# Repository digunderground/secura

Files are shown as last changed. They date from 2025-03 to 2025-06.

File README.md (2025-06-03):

###########################################################################
# Secura - Graflex Lightsaber Chassis - RELEASE
###########################################################################

## Manual 

[READ THE MANUAL HERE](Manual/README.md)

## Craft Cloud Cart 
sample cart, pay attention to the materials. you can use this cart to buy all base parts in the correct materials. 
https://craftcloud3d.com/en/offer/1f019a7e-3fd2-4ae7-9aae-cc49bfd2d0f4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

Lightsaber Render:

secura-render

Lightsaber Stand Render: 

Secura Stand-filled
https://github.com/digunderground/secura/tree/main/STL/Secura-stand

###########################################################################
##  KNOWN ISSUES - This is a WIP!!! 
###########################################################################

- the 33mm speaker (Shtok titan) requires quite a bit of thinning for the enclosure. This likely CANNOT be printed via FDM/SLA/SLS and needs to be done via SLM + nail-biting sanding.
- for FDM/SLA/SLS: you will need to merge the main battery chassis and positive (top) isolation terminal as a single print 

###########################################################################
##  Status
###########################################################################

Current Progress:
- OFFICIAL RELEASE with all assembly edits - 20250518

Past: 
- base F3d files uploaded for closed beta - 20250325
- uploaded STEP Files for non-f360 users - 20250327
- initial open source license in place - 20250325
- WIP BOM file in place for needed parts - 20250325
- pushed STL variants for people without Fusion360 - 20250325
- pushed DXF for laser cut metal pieces - 20250325
- Personal install complete - making some minor updates and will pull the project out of beta.- 20250503
- base proffie config is done and being finalized with wiring diagram - 20250503
- bespoke stand for graflex + chassis - in testing
- added a free open source saber stand for chassis and hilt

TODO:
- Update WIP BOM: tools needed, reformat doc
- direct links to purchasable carts for 3d print services and metal cutting services.
- Find contributor for CFX holder and configs
- Write or collaborate for install manual + exploded drawings etc

### The intention is to print this in SLM metal using services like:
- 316L best price: https://jlc3dp.com/
- Aluminium and other metals: https://craftcloud3d.com/

### Laser Cut metal parts have been tested from:
- https://sendcutsend.com/

### Should you choose to print this using FDM or SLA or SLS, see the notes below: 
For FDM:
- the finished product WILL lack strength in the layer direction
- you WILL lose some of the detail
- we recommend tree supports where necessarry
- you will need to merge some parts into one (positive terminal isolation) and potentially use alternate parts
- you will lose the chassis being a common ground 

For SLA:
- we recommend a 50/50 mixture of Siraya Tech Tenacious Flex and an "ABS Like Resin" - SUNLU works well
- SLA is weaker than most FDM, but has unidirectional strength
- you will need to merge some parts into one (positive terminal isolation) and potentially use alternate parts
- you will lose the chassis being a common ground 

For SLS:
- we recommend this over SLA and FDM, but still inferior to metal
- you will need to merge some parts into one (positive terminal isolation) and potentially use alternate parts
- this is the best budget option if metal is not an option for you.
- you will lose the chassis being a common ground 

###########################################################################
##  License information: 
###########################################################################

Secura Lightsaber Chassis © 2024 by PyxisVeritas LLC. is licensed under Creative Commons Attribution-NonCommercial-ShareAlike 4.0 International 

CC BY-NC-SA 4.0
This license requires that reusers give credit to the creator. 
It allows reusers to distribute, remix, adapt, and build upon the material in any medium or format, for noncommercial purposes only. 
If others modify or adapt the material, they must license the modified material under identical terms.

Additional permissions granted to Installers, Makers, Educational usage, and STEM - details available in:
https://github.com/digunderground/secura/blob/main/LICENSE

BY: Credit must be given to the creator.

NC: Only noncommercial use of your work is permitted.
Noncommercial means not primarily intended for or directed towards commercial advantage or monetary compensation.

SA: Adaptations must be shared under the same terms.

License Deed: 
https://creativecommons.org/licenses/by-nc-sa/4.0/

License Legal: 
https://creativecommons.org/licenses/by-nc-sa/4.0/legalcode.en

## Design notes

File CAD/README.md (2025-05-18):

# CAD files - OFFICIAL RELEASE
############################################################

## Usage of the Fusion 360 files is preferred for all cases

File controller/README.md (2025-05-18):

# Controller config files 
############################################################

## Proffie 3.9:  

- Base configuration for the Proffie 3.9 is live. you will need to read, understand, and add your own style functions

## TODO: 

- we need a collaborator for CFX config and model changes for CFX
- any other sound boards TBD

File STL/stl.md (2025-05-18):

# STL - Print details
###########################################################################
## Secura Chassis: 

- SLM: Any files with "ISO" in the file name should be printed in PLASTIC, they are isolation parts. DO NOT print in metal.  
- FDM/SLA you will need to merge the "CH-ISO_Battery.stl" into the main chassis
- FDM/SLA OPTIONAL: you can merge the proffie to the chassis 

## Secura Crystal Chamber: 

- SPG-window needs to be printed in CLEAR RESIN or other clear material 

## Secura Speaker: 

- SP files with "holder" in the name need to be printed in CLEAR RESIN if you want to see the lights

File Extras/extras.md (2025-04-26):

will add aupporting model files here
- board configurator will be uploaded 2025-04-26

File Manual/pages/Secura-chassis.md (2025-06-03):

# Secura Chassis 
_electronics and battery_
***
## Navigation: [Manual](../README.md) / Secura-chassis.md
***
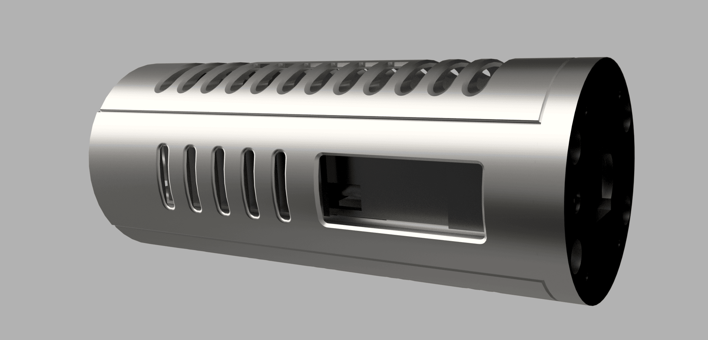
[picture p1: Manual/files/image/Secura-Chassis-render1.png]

***
https://github.com/user-attachments/assets/cefb1376-12e1-43ca-87cb-c5749daabf90
***
## Chassis Part Highlights: 
> [!CAUTION]
> All parts with "..ISO.." in the name are isolation parts and must be printed in approved plastics

> [!IMPORTANT]
>It is our strong recommendation to have the chassis parts SLM printed from metal 

***

## TOC 
[Manual](../README.md) / Secura-chassis.md
***
### 1) Isolation parts - print out of a non-conductive material 
- [CH-ISO_Battery ](#ch-iso_battery)
- [CH-ISO_Proffie](#ch-iso_proffie)
- [CH-ISO_BusBar](#ch-iso_busbar)
- [CH-ISO_screen](#ch-iso_screen) 

### 2) Main Body Parts - SLM > SLS > SLA or FDM 
- [CH-base](#ch-base)
- [CH-electronicsDoor](#ch-electronicsdoor)
- [CH-chassis](#ch-chassis)
- [CH-batteryDoor](#ch-batterydoor)

> [!CAUTION]
> DO NOT PRINT CH-batteryTerminal. this is for sizing and comparison - [CH-ISO_Battery ](#ch-iso_battery) has a full description.

## CH-ISO_Battery
***
[to TOC &uarr;](#toc)
***
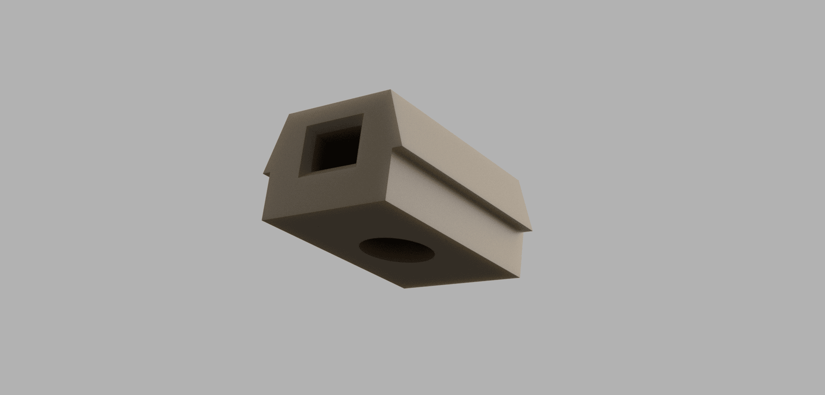
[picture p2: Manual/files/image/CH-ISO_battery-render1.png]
 
> [!IMPORTANT]
> If you choose to print the entire chassis out plastic instead of metal, this part will need to be merged into the CH-chassis part for ideal rigidity.

The CH-ISO_battery part isolates the battery positive contact from the SLM metal chassis. You will need a piece of 5mm Copper rod to cut a positive battery contact out of, you can use a dremel tool to do this. 
Once the positive terminal is cut out it can be notched and soldered to the wire, then pressed into the CH-ISO-Battery part with the wire exiting the rectangular hole in the rear. 
- we recommend printing this part out of PA12 or PA6 using a SLS method 
- alternatively you can FDM print from PA12 or ABS/ASA 

## CH-ISO_Proffie
*** 
[to TOC &uarr;](#toc)
***
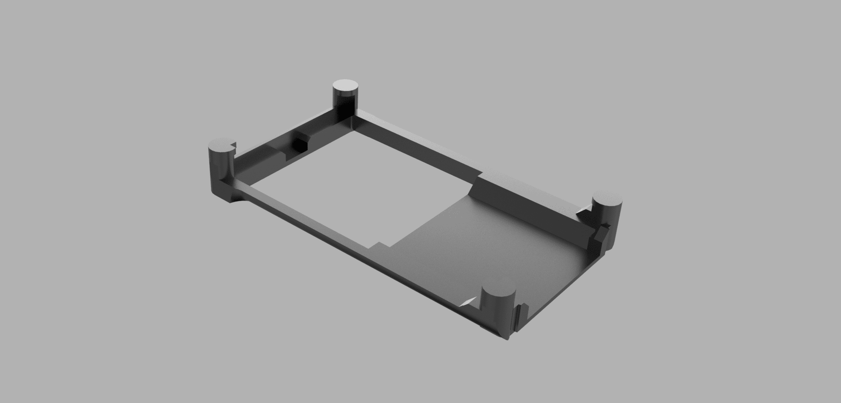
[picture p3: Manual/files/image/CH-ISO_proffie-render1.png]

> [!NOTE]
> The Proffie is mounted with the SD card facing the mount. 

The CH-ISO_proffie part isolates the proffie from the SLM metal chassis. The proffie board is a snug fit, some filing or clipping to the "posts" may be needed depending on the printer accuracy.
this part can be glued to the chassis body (CH-chassis) to improve rigidity, but it will press into place as-is. 
- we recommend printing this part out of PA12 or PA6 using a SLS method
- alternatively you can FDM print from PA12 or ABS/ASA

## CH-ISO_BusBar
***
[to TOC &uarr;](#toc)
***
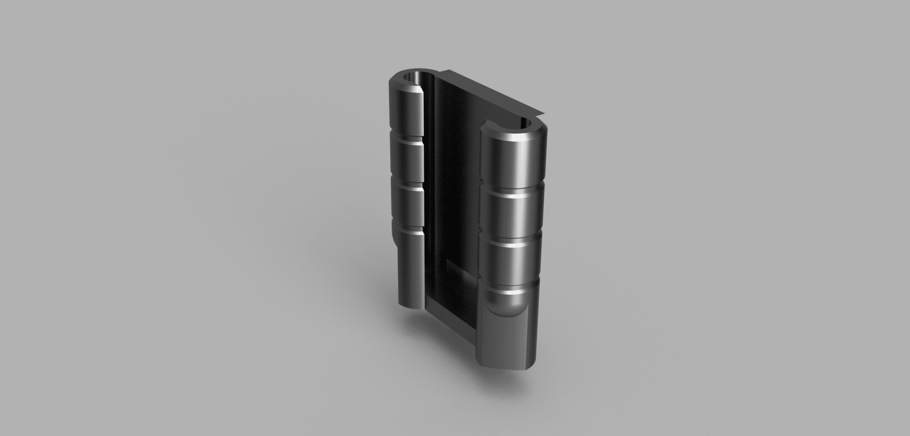
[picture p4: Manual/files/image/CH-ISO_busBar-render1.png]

> [!TIP]
> this is an OPTIONAL part 

The CH-ISO_busBar part is optional, it is intended to use 2x 3mm copper tubes as the positive and negative common. This allows installers to have a clean way to tie multiple leads to positive or negative to drive various components. 
this can wholly be omitted in favor of wire heat shrink and tucking. 
Should you choose to use this part you will need 3mm thick wall copper tubing, cut to length and solder points cut/drilled in the tube to support the number of connections you need. 

## CH-ISO_Screen
*** 
[to TOC &uarr;](#toc)
***
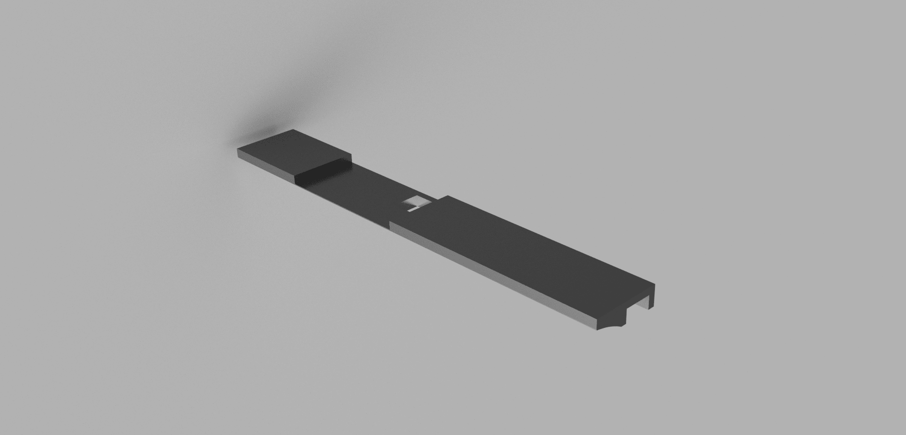
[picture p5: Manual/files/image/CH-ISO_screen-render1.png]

> [!NOTE]
> The screen is mounted to the topside with wires running behind it. additionally, a LED strip can be affixed to the top side to show through the chassis venting. 

The CH-ISO_screen part is to keep the OLED isolated from the SLM metal chassis body. it also allows the wires to run behind it, concealing them from view. This part provides a snug fit for the screen against the main chassis. 
> [!TIP]
> you may need to sand down thi part of a perfect fit depending on how much finish work you put into the SLM metal body. 

## CH-base
*** 
[to TOC &uarr;](#toc)
***
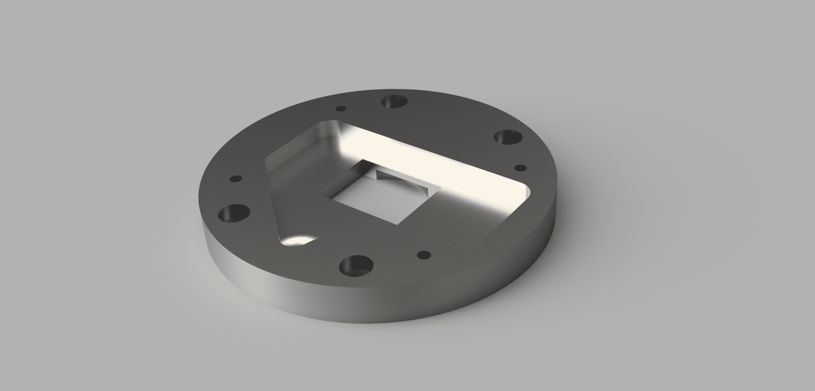
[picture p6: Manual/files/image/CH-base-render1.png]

> [!IMPORTANT]
> you will need to tap 4x M1.4 holes in this piece to hold the speaker enclosure 

> [!TIP]
> Assemble calls for 4x 4-40 heatset inserts - these are NOT heat set into the parts, it is instead used as a very small nut that will easily recess into the part when assembled. 

The CH-base part caps off the bottom end of the chassis assembly and allows the speaker holder to be secure screwed in using 4x M1.4 screws. This part has an opening that you can mount a single LED or small Shtok LED ring into. 
the recessed side (in the image) goes towards the chassis, this area is to allow easy routing of electronics and wires

## CH-electronicsDoor
*** 
[to TOC &uarr;](#toc)
***
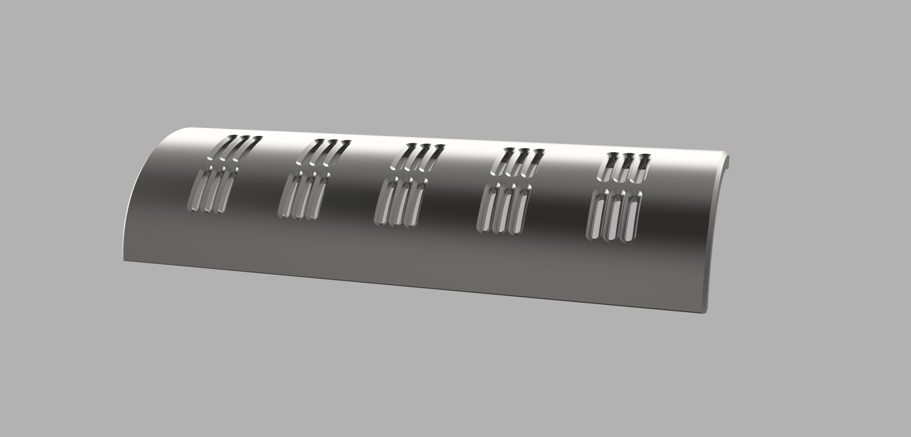
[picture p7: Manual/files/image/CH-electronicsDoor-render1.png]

> [!NOTE]
> This part is NOT interchangable with the CH-batteryDoor

> [!TIP]
> you will need to glue in 6x neodymium magnets - 3mm diameter 1mm thick 

This part covers the electronics of the chassis, it is held on with 6x neodymium magnets that you need to glue in. be VERY cautious during install to keep the magnets in the correct orientation so they do not repel the magnets in the CH-chassis part - these small magnets really like to flip flop. 

## CH-chassis
*** 
[to TOC &uarr;](#toc)
***
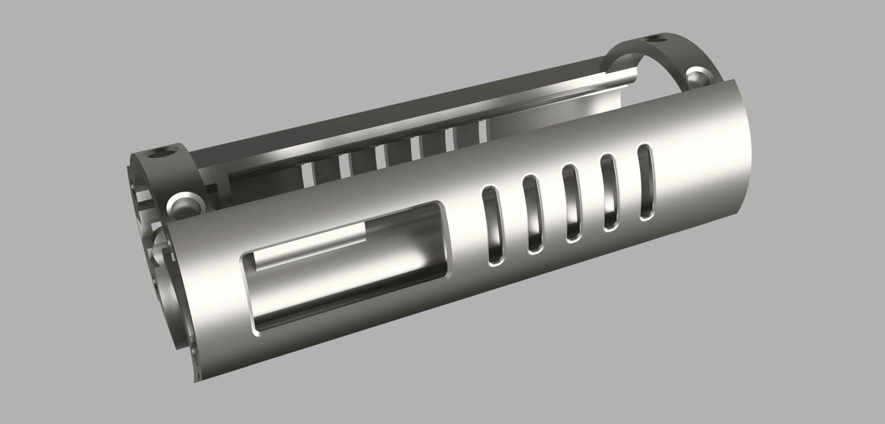
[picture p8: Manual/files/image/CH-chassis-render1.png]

> [!NOTE]
> This will require 10x neodymium magnets 3mm diameter x 2mm thick 

The CH-chassis part is the main event, here to house all electronics and wiring. it is a tight fit and will test your patience from time to time. 

## CH-batteryDoor
*** 
[to TOC &uarr;](#toc)
***
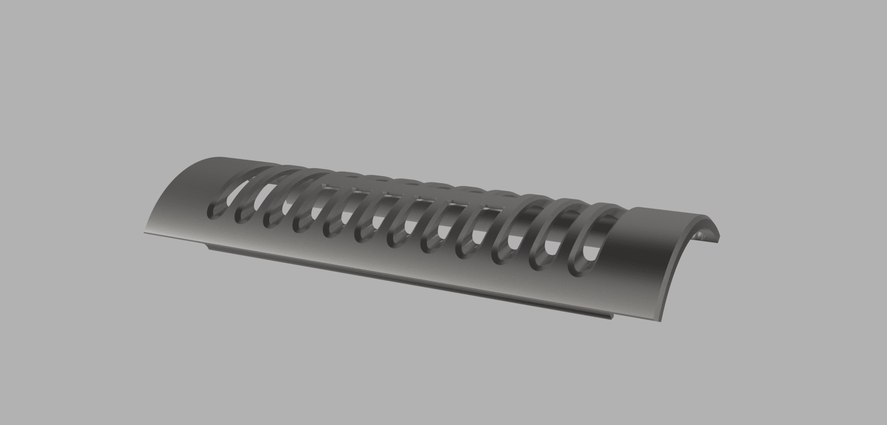
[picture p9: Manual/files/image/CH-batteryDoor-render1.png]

> [!NOTE]
> This part is NOT interchangable with the CH-electronicsDoor

> [!TIP]
> you will need to glue in 4x neodymium magnets - 3mm diameter 1mm thick

This part covers the battery within chassis, it is held on with 4x neodymium magnets that you need to glue in. Be VERY cautious during install to keep the magnets in the correct orientation so they do not repel the magnets in the CH-chassis part - these small magnets really like to flip flop.

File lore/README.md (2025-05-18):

https://github.com/user-attachments/assets/b904147c-5c41-4c31-8f6f-022a52ba4b2a

# SECURA LORE 
################################################################

As a Padawan, Anakin Skywalker built his first lightsaber with great pride, believing it to be the finest weapon crafted by any Jedi. It did not last. In the depths of a Separatist droid foundry on Geonosis, he lost it—severed by a mechanical cutting arm as easily as the factory carved its machines of war. That was the nature of Anakin Skywalker: to build something powerful, only to lose it in his recklessness.

When the time came to construct a second saber, Anakin sought perfection. He had seen battle by then, had fought alongside Jedi whose skills in lightsaber construction surpassed his own. Among them was Aayla Secura. She was not merely a warrior—she was an artist with a blade, both in combat and in its design. Unlike most Jedi, who constructed their weapons once and rarely modified them, Aayla refined hers constantly, always improving its internals. She had developed a specialized chassis system, reinforcing the weapon’s power flow with stabilizers that increased energy efficiency and minimized strain on the Kyber crystal. This allowed her lightsaber to maintain perfect balance in combat, the energy output steady and unyielding even under extreme conditions. It was built for endurance, for adaptability—something that intrigued Anakin greatly.

Between battles, he studied her weapon closely, often asking questions about its construction. At first, she humored him, explaining the intricacies of her modifications. But as time passed, she realized he was not merely curious—he was absorbing everything she said, eager to apply it to his own work. He spent hours in quiet observation, watching how she fine-tuned the chassis, how she adjusted the focusing crystal to prevent degradation, how the modular framework allowed for easy repair and adaptation. It was a level of craftsmanship beyond his own at the time, and though he would never openly admit it, Aayla had become an unintentional mentor to him.

But Aayla's time in the war was not endless. On Felucia, as Order 66 was enacted, betrayal struck swiftly. Commander Bly and his troops turned on her without hesitation, their blasters raining fire upon her. With no time to defend herself, Aayla fell, her body left behind as the clones marched on. Her lightsaber, a testament to her ingenuity and skill, was lost to the jungle.

Anakin survived, though not as the Jedi he had once been. When he built his second lightsaber, he drew upon the lessons he had learned from Aayla. It was no mere reconstruction of his first weapon; it was stronger, more efficient, its internal architecture stabilized by principles he had taken from her work. It carried echoes of her innovations, a silent tribute to a Jedi he would never fight alongside again. He wielded it through victories and defeats, through moments of heroism and the first whispers of his fall.

Then, on Mustafar, the weapon fell from his grasp as Obi-Wan Kenobi struck him down. His former Master, standing above him on the lava banks, did not hesitate—he took the lightsaber, knowing its importance. But as he held it, he felt something deeper than just Anakin’s presence. He had fought alongside Aayla in the Clone Wars, had seen her skill firsthand, and as he turned the weapon in his hands, he recognized elements of her craft woven into its construction. This was no ordinary blade. It had passed through the hands of warriors who had shaped the fate of the Republic.

Obi-Wan fled to Tatooine, taking the lightsaber with him. He could not bring himself to destroy it, nor could he wield it himself—it was not his to bear. Instead, he hid it away, keeping it safe until the time was right. In exile, he often thought of the past—of Anakin, of Aayla, of all the Jedi lost to the Empire. He knew the lightsaber would one day have a purpose, that it would not remain buried forever.

And when the time came, and he placed it in the hands of Luke Skywalker, he did so knowing it was more than just a weapon. It was a legacy—not just of Anakin Skywalker, but of Aayla Secura, of the Jedi who came before, of the fight to restore balance to the Force. The saber had passed through war and betrayal, through loss and exile. Now, it would help guide the galaxy toward hope once more.

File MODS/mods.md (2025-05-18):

# MODS - all USER content / Contributions
###################################################################

## Rules: 

### For Mods: 
- branch and check out main codebase
- create a folder withing /MODS/ using your GIT username. IE: /MODS/myUserName/
- keep the root folder structure 
- make your mods/edits/changes/contributions

### For updates to the core (fixes, QOL): 

- ONLY if you want to have a feature pulled into MAIN:
  - post a PR (pull request) for a branch 
  - only include the changes you are recommending that fix a base feature 
  - have VERY detailed GIT check in comments - this will make or break your request!!!!

### OVERALL: 
- be patient, we are a small team. wait for approval and validation. 
- In some cases, mods will be merged back to the main project and you may be invited as a contributor.

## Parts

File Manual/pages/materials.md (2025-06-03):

# Materials
***
## Navigation: [Manual](../README.md) / materials.md 
***
## TOC
[Manual](../README.md) / materials.md
- [FDM / SLS Materials ](#fdmsls-materials)
- [Metal Materials](#metal-materials) (SLM)
- [Resin Materials](#resin-materials)

***
## FDM/SLS materials 
***
> [!IMPORTANT]
> - Ideally FDM/SLS are only used for the ISO (isolation) parts
> - A full SLS/FDM chassis will work but will be significantly less rigid.
> - you will need to merge some parts for a full resin chassis.

| **MATERIAL** | **METHOD** | **APPROVAL** | **TESTED** | **NOTES** |
|---|---|---|---|---|
| PA12 | SLS/FDM | YES | YES | non-condustive, resistant to heat, does not deform over time |
| PA6 | SLS/FDM | YES | YES | non-condustive, resistant to heat, does not deform over time |
| ABS | FDM | YES | YES | non-condustive, resistant to heat, does not deform over time |
| ASA | FDM | YES | YES | non-condustive, resistant to heat, does not deform over time |
| PLA | FDM | NO | YES | Non-Condustive, deforms under heat, deforms over time |
| PETG | FDM | NO | YES | Non-Conductive, Handles heat well, deforms over time, not ideal |
| ANY Carbon Reinforced | SLS/FDM | NO | YES | POTENTIALLY conductive - DO NOT USE |
| PC (polycarbonate) | FDM | YES | YES | non-condustive, resistant to heat, does not deform over time |
| PEEK | FDM | YES | NO | Of course this will work, you are borderline crazy |

> [!NOTE]
> This is NOT an exhaustive list, other materials may work.
> List will be updated over time

[to TOC &uarr;](#toc)

## Metal materials
***

> [!IMPORTANT]  
> - we have only tested SLM due to its strength and ability to be machined if needed. 
> - we have NOT tested DMLS / LMM / DMP / or Binder Jet - due to costs, availability or known limitations

| **MATERIAL** | **METHOD** | **IMPACT** | **TESTED** | **NOTES** | **EXAMPLE COST** |
|---|---|---|---|---|---|
| Stainless 316 | SLM | Harder | YES | Durable, difficult to work with, moderate expense | $180 |
| Aluminum | SLM | Easy | YES | Moderately Durable, easy to work with, low expense | $160 |
| Brass | SLM | Expensive  | NO | Moderately durable, easy to work with, very high expense | over $1000 |
| Copper | SLM | Expensive  | NO | Moderately durable, difficult to work with, very high expense | over $1000 |
| Bronze | SLM | Expensive  | NO | Durable, difficult to work with, very high expense | over $1000 |
| Titanium | SLM | Expert | YES | Extremely durable, very difficult to work with, high expense  | $675 |

> [!NOTE]
> This is NOT an exhaustive list, other materials may work.
> List will be updated over time

[to TOC &uarr;](#toc)

## Resin materials
***
> [!IMPORTANT]
> - Resin should NOT used for the ISO (isolation) parts due to their tendency to fracture
> - A full resin chassis will work but will be significantly less rigid and prone to cracking.
> - you will need to merge some parts for a full resin chassis.

| **MATERIAL** | **METHOD** | **APPROVAL** | **TESTED** | **NOTES** |
|---|---|---|---|---|
| Nylon Like | SLA | YES | YES | relatively durable, less prone to cracking |
| ABS Like | SLA | YES | YES | relatively durable, less prone to cracking |
| Siraya Tech Tenacious Flex | SLA | NO | YES | difficult to print details, durable, flexible |
| 50/50 ABS/Siraya Tech Tenacious Flex | SLA | YES | YES | durable, relatively easy to print, best option for SLA |
| RESIONE G217 Clear ABS-Like Resin | SLA | CLEAR ONLY | YES | Great for clear parts after sanding and polishing, not recommended for the full chassis |

> [!NOTE]
> This is NOT an exhaustive list, other materials may work.
> List will be updated over time

[to TOC &uarr;](#toc)

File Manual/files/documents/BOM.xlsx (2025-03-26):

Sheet: Hardware
Required | Related part | Description | Supplier | SKU/Model | URL | Cost | Quantity | Notes:
yes | side switch - emitter | Lever Microminiature Microswitch SPDT Body dimensions: 8.3 x 6.5 x 2.7mm (height x length x width) | switchelectronics | SKU: 483501 MPN: 483501 | https://www.switchelectronics.co.uk/products/lever-microminiature-microswitch-spdt?variant=45339140423989 | $1.25 | 1 | price per. Extras are always a good idea.
optional | crystal chamber top/bottom | Splined Press-Fit Threaded Standoffs 4-40 | McMaster Carr | 92985A110 | https://www.mcmaster.com/catalog/131/3746/92985A110 | $14.70 | 1 | pack of 25
yes | emitter button | Titanium Phillips Flat Head Screws | McMaster Carr | 90233A400 | https://www.mcmaster.com/catalog/131/3496/90233A400 | $1.52 | 1 | extras are always good
optional | crystal chamber top/bottom | Titanium Unthreaded Spacers | McMaster Carr | 98721A112 | https://www.mcmaster.com/catalog/131/3729/98721A112 | $4.08 | 24
yes | Speaker holder | M1.4 316 Stainless Steel Socket Head Screws | McMaster Carr | 92290A846 | https://www.mcmaster.com/catalog/131/3569/92290A846 | $13.43 | 1 | pack of 25
yes | speaker cover | m1.4 18-8 Stainless Steel Slotted Flat Head Screws | McMaster Carr | 91430A156 | https://www.mcmaster.com/catalog/131/3503/91430A156 | $12.00 | 1 | pack of 10
yes | chassis | Micro Momentary Tactile Push Button Switch Tact Assortment Kit | Amazon | 602318745965 | https://www.amazon.com/dp/B07LCBLB8N?ref_=ppx_hzsearch_conn_dt_b_fed_asin_title_2&th=1 | $9.49 | 1 | more than you need
yes | chassis | Proffieboard v3.9 Soundcard | thecustomsabershop | Proffieboard v3.9 | https://www.thecustomsabershop.com/Electronics/Sound-Modules/Proffieboard-v39-Soundcard | $48.00 | 1 | any vendor is acceptible
yes | chassis | 4W 28mm WOWSpeaker | thecustomsabershop | 28mm speaker | https://www.thecustomsabershop.com/Electronics/Speakers/28mm-Speakers/4W-28mm-WOWSpeaker | $12.95 | 1 | this fits, others may work
yes | blade holder | NPXL V3 Hilt side PCB connector - Long Pins | thecustomsabershop | NPXL V3 | https://www.thecustomsabershop.com/Blades/Pixel-Blades/Pixel-Blade-Components/NPXL-Style-Connector/NPXL-V3-Hilt-side-PCB-connector-Long-Pins | $15.10 | 1 | others may fit
yes | blade holder | 1" NPXL V3 Hilt Side Adapter | thecustomsabershop |  | https://www.thecustomsabershop.com/Blades/Pixel-Blades/Pixel-Blade-Components/NPXL-Style-Connector/1-NPXL-V3-Hilt-Side-Adapter | $4.20 | 1
yes | chassis | USB-C Breakout Board | thecustomsabershop |  | https://www.thecustomsabershop.com/Electronics/Batteries-and-Packs/Clips-Connectors/USB-C-Breakout-Board | $5.50 | 1
yes | chassis | OLED screen | thecustomsabershop |  | https://www.thecustomsabershop.com/Electronics/Sound-Modules/OLED-Screen-Blue | $6.25 | 1
yes | Crystal chamber | 2.7mm Ultra Narrow LED Strip | Amazon |  | https://www.amazon.com/dp/B0CYGHHR96?ref=ppx_yo2ov_dt_b_fed_asin_title&th=1 | $15.99 | 1
yes | chassis | 8650 Battery Negative to Positive Conversion Spring Contact | Amazon |  | https://www.amazon.com/uxcell-Negative-Conversion-Nickeling-16-5mmx16mm/dp/B07HRTMY5T | $12.19 | 1
yes | chassis | #3-48 Tap and #47 Drill Bit Kit | Amazon |  | https://www.amazon.com/dp/B071D7FWC9?ref=ppx_yo2ov_dt_b_fed_asin_title | $8.13 | 1
yes | chassis | #4-40 Tap and #43 Drill Bit Kit | Amazon |  | https://www.amazon.com/dp/B071DHVB6S?ref=ppx_yo2ov_dt_b_fed_asin_title&th=1 | $10.13 | 1
yes | crystal chamber | 4-40 Tapered, Thru-Threaded, 4.4 mm OD, 3.4 mm Length | Amazon |  | https://www.amazon.com/dp/B08WC192B9?ref=ppx_yo2ov_dt_b_fed_asin_title | $15.98 | 1
yes | crystal chamber | 6mm Mini Micro Planetary Reduction High Electric Micro Speed Reduction Gear Motor DC3V Motor(Three Stage) | Amazon |  | https://www.amazon.com/dp/B0863D37XN?ref=ppx_yo2ov_dt_b_fed_asin_title | $12.87 | 1
 |  |  |  |  |  | $223.76

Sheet: 3D part Supplier
Supplier | Material | Process | parts | Cost | Notes:
https://craftcloud3d.com/ | Aluminum | SLM | chassis | $180.00 | electro anodize for additional colors
 | 316L | SLM | chassis | $330.00
 | Titanium | SLM | chassis | $740.00
 | Copper/brass/bronze | SLM | chassis | $1800.00 | starts at $1800 - ranges to a used car. Use TI instead and anodize
 | PA12 | SLS | isolation | $22.00
 | Transparent resin | SLA | speaker holder | $40.00 | worst price
https://jlcpcb.com/ | 316L | SLM | chassis | $163.00 | by far the best pricing, long lead time
 | PA12 | SLS | isolation | $2.00 | best pricing
 | transparent resin | SLA | speaker holder | $2.40 | best pricing

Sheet: Wiring
Device | Proffie 3.9 Pins | Description | wire type | Gauge | Notes
Main Blade |  |  |  |  | Designed for up to 20A (quad pixel blde)
 | (22) LED 3 | negative | PTFE | 18
 | (22) LED 2 | negative | PTFE | 18
 | BUS | positive | PTFE | 18
 | (6) Data 4 | Data | PTFE | 30 | blade removal
 | (0,1) Data1/ID | Data |  | 30
SPG LED | (20) LED1 | Negative |  | 30
 | Data2 (2,3) | Data |  | 30
 | BUS | positive |  | 30
Button (main) | BUS | Negative |  | 30
 | Button1 (11,12) | positive |  | 30
Button (side) | BUS | Negative |  | 30
 | (13,14) button2 | positive |  | 30
OLED | SDA (18) | Data |  | 30 | Connects to SCK on OLED
 | SCL (19) | Data |  | 30 | Connects to SDA on OLED
 | SD Power | Positive |  | 30
 | BUS | Negative |  | 30
Speaker | Speaker + | Positive |  | 28
 | Speaker - | Negative |  | 28
Crystal Chamber LED | BUS | Positive |  | 30
 | LED6 (25) | Negative |  | 30
 | Data3 (4,5) | Data |  | 30
SPG motor (3 step) | 3.3v | Positive |  | 30
 | LED4 (23) | Negative |  | 30
Speaker LED | (24) LED5 | Negative |  | 30
 | BUS | Positive |  | 30
 | Free3 (9,10) | Data |  | 30 | Free1 (7) alt

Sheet: Open Source License
https://creativecommons.org/licenses/by-nc-sa/4.0/
Secura Lightsaber Chassis © 2024 by PyxisVeritas LLC is licensed under Creative Commons Attribution-NonCommercial-ShareAlike 4.0 International

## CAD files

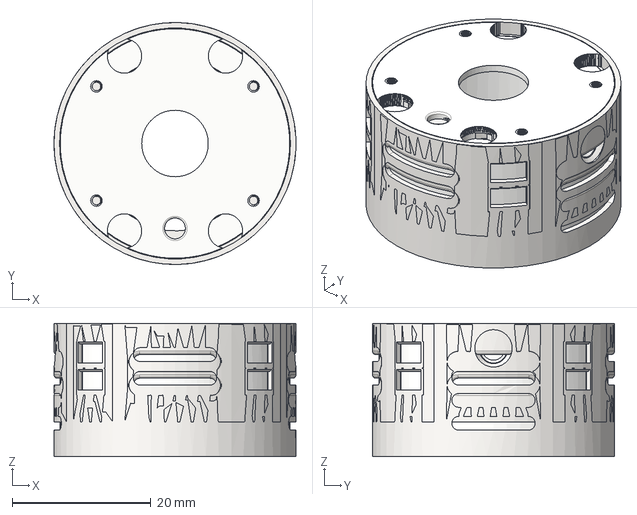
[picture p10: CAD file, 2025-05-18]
CAD/STEP/Secura-Speaker.step
34.9 x 34.9 x 19.2 mm

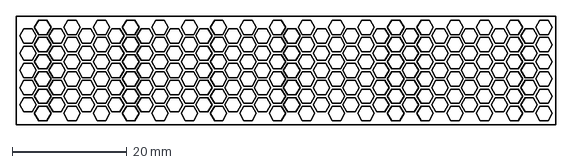
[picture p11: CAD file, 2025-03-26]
DXF/Secura-pg-hex-mesh.dxf
94.0 x 19.0 mm

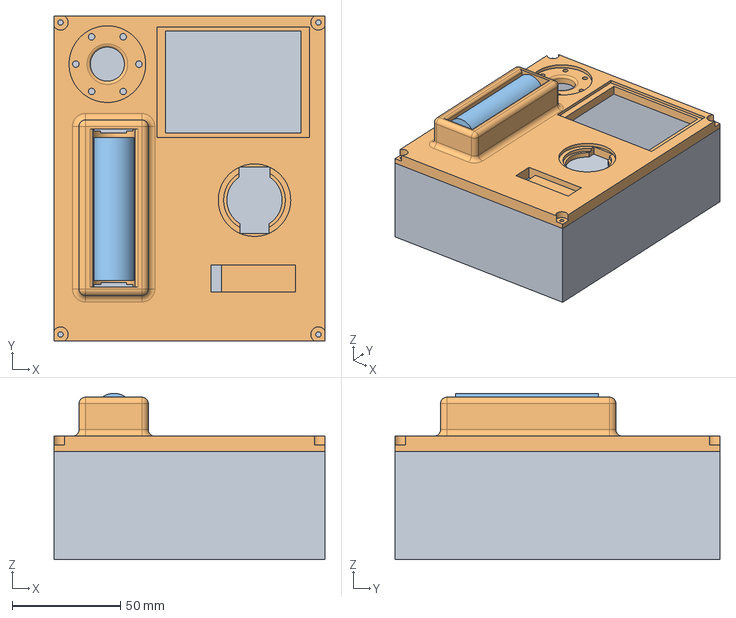
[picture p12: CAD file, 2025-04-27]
Extras/proffieTester/STEP/wiring_tester_v5_wiring_tester_v5.step
125.0 x 150.0 x 76.7 mm

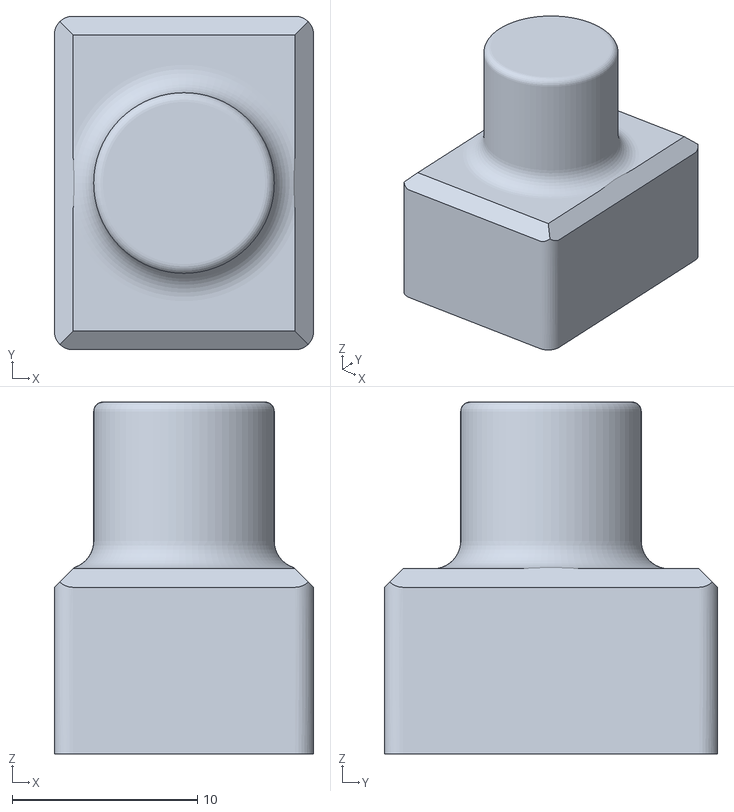
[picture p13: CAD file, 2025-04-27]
Extras/proffieTester/STL/wiring_tester_v5_magnet.stl
14.0 x 18.0 x 19.0

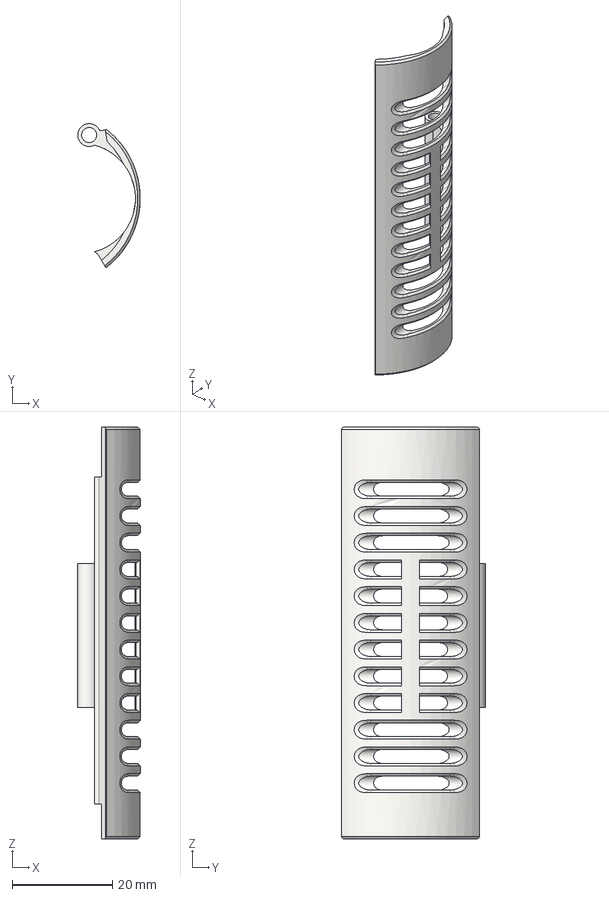
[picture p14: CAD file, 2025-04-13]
MODS/Digunderground/experimental/Secura-chassis/Secura-CH-EXP-21700-batteryDoor.step
12.4 x 28.6 x 82.0 mm

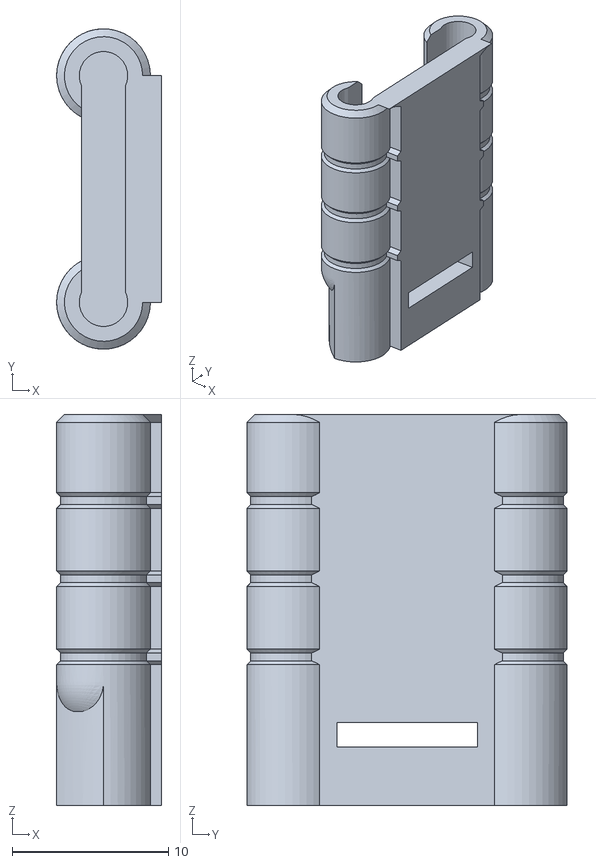
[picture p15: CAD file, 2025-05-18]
STL/Secura-chassis/CH-ISO_bus_bar.stl
6.70 x 20.5 x 25.0

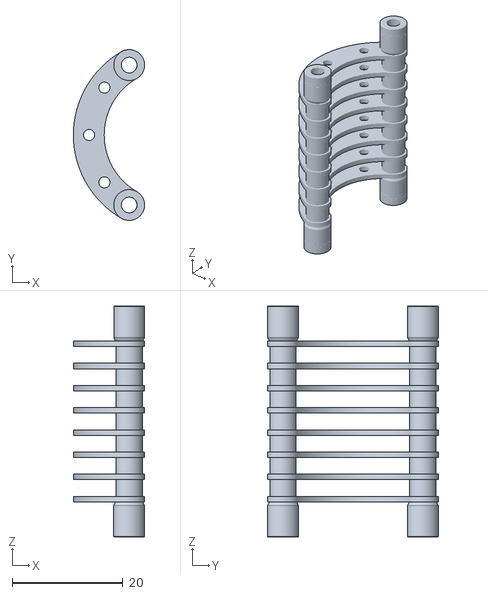
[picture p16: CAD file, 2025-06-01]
STL/Secura-crystalChamber/NOP/NOP-CC-fins-l.stl
12.8 x 30.8 x 41.6

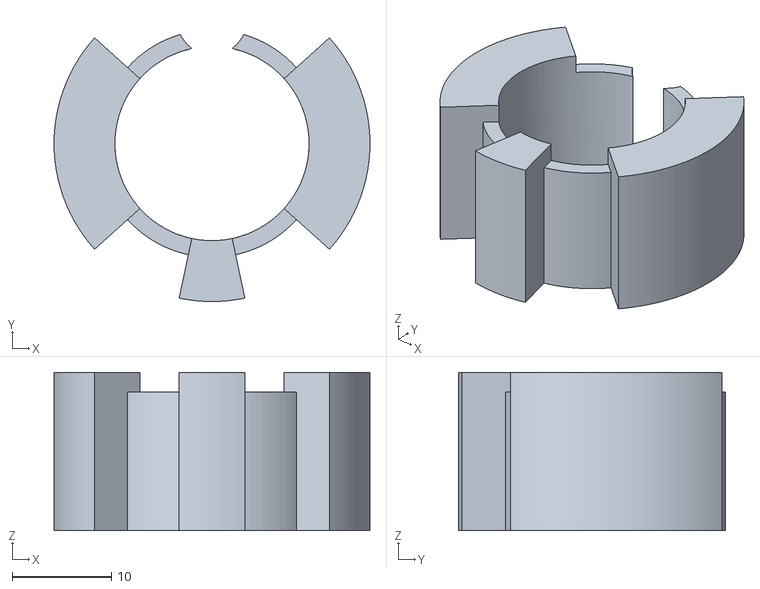
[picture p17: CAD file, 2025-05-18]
STL/Secura-crystalChamber/SPG-window.stl
31.9 x 27.0 x 16.0

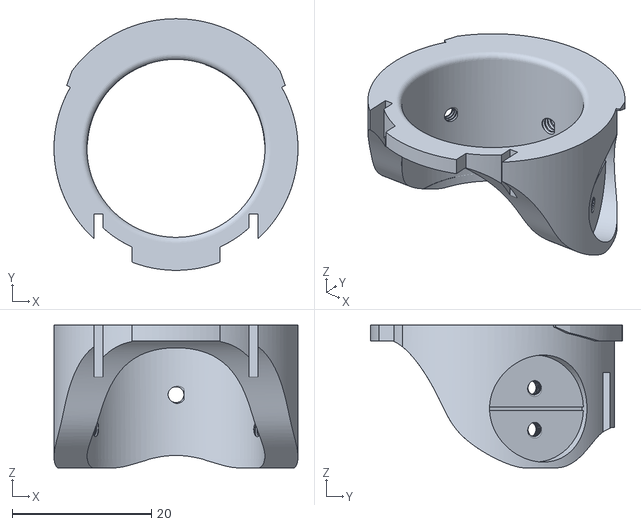
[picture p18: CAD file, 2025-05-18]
STL/Secura-emitter/EM-topAccurate.stl
35.1 x 36.2 x 20.5

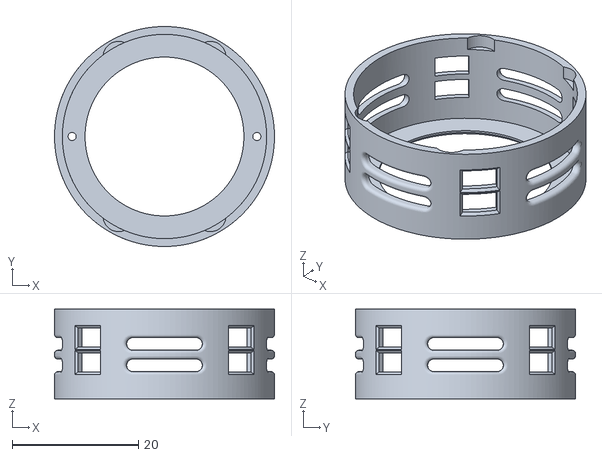
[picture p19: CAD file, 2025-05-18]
STL/Secura-speaker/28mm/SP-28mm-outer.stl
34.9 x 34.9 x 14.2

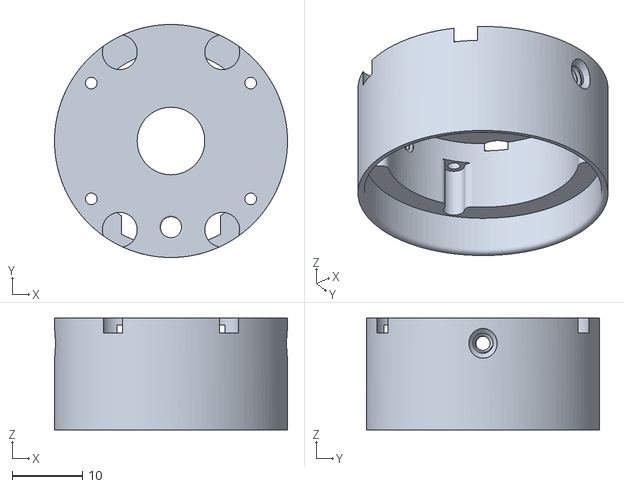
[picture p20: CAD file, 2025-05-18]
STL/Secura-speaker/33mm/SP-33mm-holder.stl
33.1 x 33.1 x 15.9

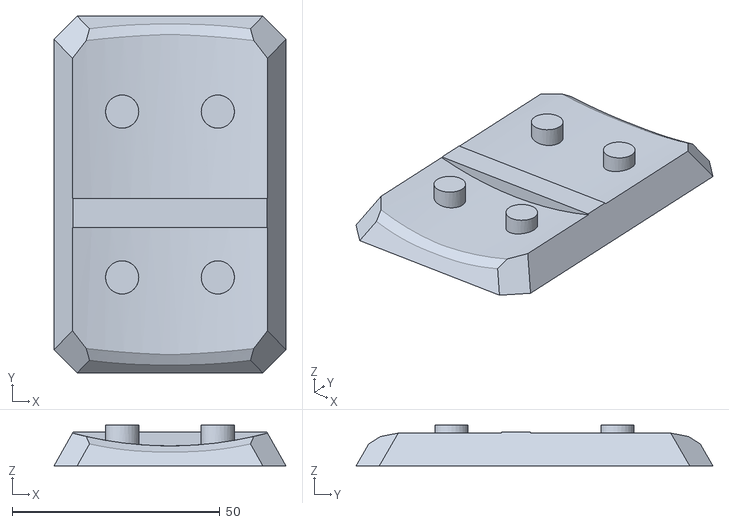
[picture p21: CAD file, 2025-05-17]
STL/Secura-stand/SS-arcHolder.stl
55.8 x 85.9 x 9.80

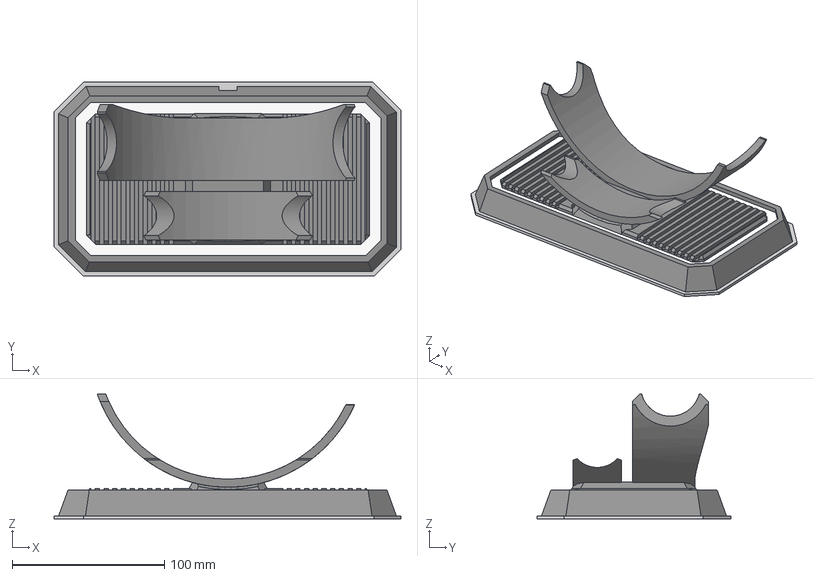
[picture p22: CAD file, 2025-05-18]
CAD/STEP/Secura-stand.step
227.6 x 127.4 x 81.9 mm

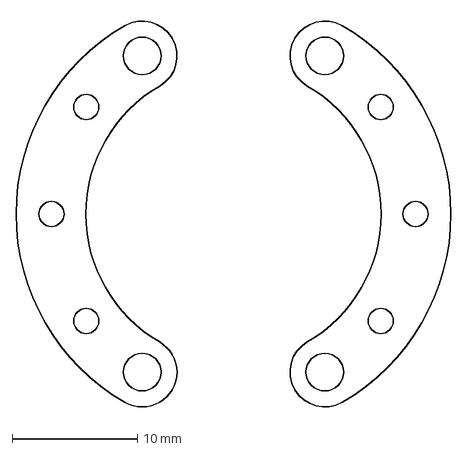
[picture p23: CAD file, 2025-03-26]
DXF/Secura-cc-fins.dxf
34.7 x 31.6 mm

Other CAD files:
Extras/proffieTester/STL/wiring_tester_v5_test-bottom.stl
MODS/Digunderground/experimental/Secura-chassis/Secura-CH-EXP-21700-Chassis.step
STL/Secura-chassis/CH-chassis.stl
STL/Secura-crystalChamber/NOP/NOP-CC-fins-r.stl
CAD/Fusion360/Secura-Chassis.f3d
CAD/Fusion360/Secura-CrystalChamber.f3d
CAD/Fusion360/Secura-Emitter.f3d
CAD/Fusion360/Secura-Speaker.f3d
CAD/Fusion360/Secura-stand.f3d
CAD/STEP/Secura-CrystalChamber.step
Extras/proffieTester/STL/wiring_tester_v5_faux-18650.stl
Extras/proffieTester/STL/wiring_tester_v5_test-top.stl
MODS/Digunderground/STL/Secura-emitter/EM-base-thumbScrew.stl
MODS/Digunderground/experimental/Secura-chassis/CH - Chassis-21700.stl
MODS/Digunderground/experimental/Secura-chassis/CH - battery door- 21700.stl
STL/Secura-chassis/CH-ISO_Battery.stl
STL/Secura-chassis/CH-ISO_Proffie.stl
STL/Secura-chassis/CH-ISO_screen.stl
STL/Secura-chassis/CH-base.stl
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

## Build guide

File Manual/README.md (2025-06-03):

# Secura Chassis Manual
***
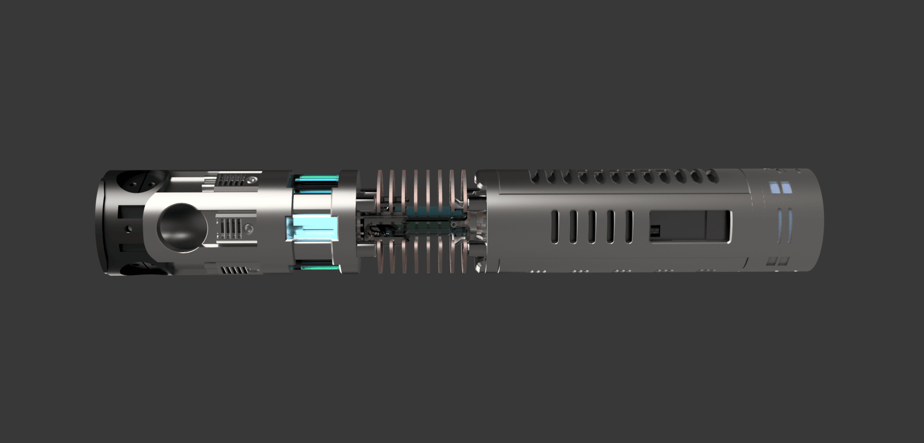
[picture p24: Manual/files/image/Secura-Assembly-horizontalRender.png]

## Main Chassis Parts: 
This manual will be broken into sections for each main component and their assembly details. 
There will be additional sections for various other assembly and wiring needs. 
***

> [!IMPORTANT]
> - Files OR Folders with NOP mean "NoPrint" - these are for reference or people who want to print these parts instead of using hardware or laser cut parts. These are generally untested in a printable form and intended to use parts from the BOM instead. 

## Glossary: 

- ### Part descriptions and details 
  - [Secura Chassis ](pages/Secura-chassis.md)
  - [Secura Crystal Chamber and Plasma Gate](pages/Secura-crystalChamber.md)
  - [Secura Emitter ](pages/Secura-emitter.md)
  - [Secura Speaker](pages/Secura-speaker.md)
- ### Assembly Documentation 
  - #### General 
    - [Materials](pages/materials.md) (Recommended 3d printing materials)
    - [Tools and Consumables](pages/tools-consumables.md) (recommended Tools)
    - Finishing Parts
    - [Wiring](pages/wiring.md)
    - Tapping
    - Suppliers
  
  - #### Secura Chassis Assembly 
    - [Secura Chassis ](pages/Secura-chassis-assembly.md)
    - [Secura Crystal Chamber and Plasma Gate](pages/Secura-crystalChamber-assembly.md)
    - [Secura Emitter ](pages/Secura-emitter-assembly.md)
    - [Secura Speaker](pages/Secura-speaker-assembly.md)

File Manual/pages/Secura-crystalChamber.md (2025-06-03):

# Secura Crystal Chamber
_Blade holder, buttons and chassis side blade pins_
***
## Navigation: [Manual](../README.md) / Secura-crystalChamber.md
***
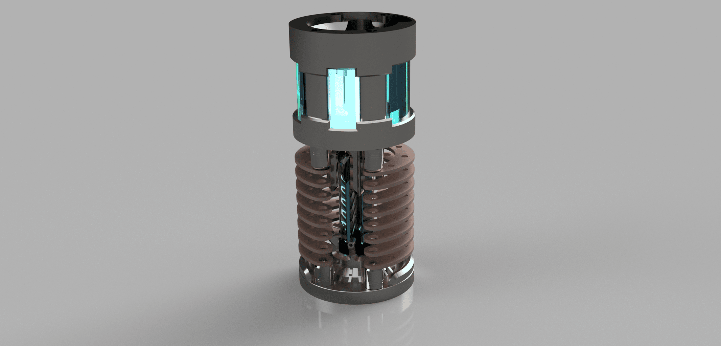
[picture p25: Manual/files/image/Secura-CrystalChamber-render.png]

***

https://github.com/user-attachments/assets/aa2abbda-b485-40cf-995b-76118d8b39da

***
## Crystal Chamber Part Highlights:

> [!IMPORTANT]
> - It is our strong recommendation to have the chassis parts SLM printed from metal
> - The "cooling fins" should be laser cut - you can print these but it is not rigid.

***

## TOC
[Manual](../README.md) / Secura-crystalChamber.md
- [SPG-top](#spg-top)
- [SPG-window](#spg-window)
- [SPG-reactor](#spg-reactor)
- [SPG-base](#spg-base)
- [SPG-collector](#spg-collector)
- [CC-base](#cc-base)
- [CC-fins](#cc-fins)

## SPG-top
***
[to TOC &uarr;](#toc)
***
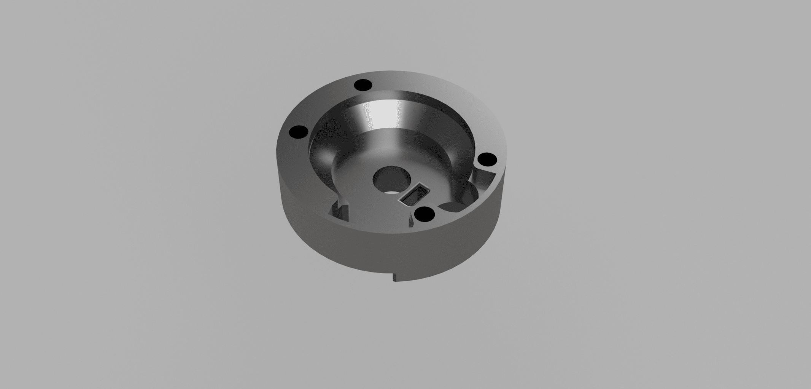
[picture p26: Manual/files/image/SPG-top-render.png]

> [!IMPORTANT]
> - you may need some filing/sanding to fit the hilt-side pixel PCB. do not sand too much, it should snap in with glue as optional.
> - use a piece of marble tile (flat surface - "poor mans" surface plate ) to flatten the mating surface 

> [!NOTE]
> - Assembly of this part is tedious 
> - This (with the window and SPG-base) houses the hilt side pixel pcb, 3-stage micro motor, LEDs for plasma gate, and switch wiring. 
> - You can use a single or dual stage motor for faster plasma gate spinning, but a 3 stage is recommended. 

You must build the entire plasma gate assembly and install it in one piece - test the components once assembled to ensure everything is smooth and moves freely. 
Once assembled, this slides onto the 4-40 rods mounted in the emitter section 

## SPG-window
***
[to TOC &uarr;](#toc)
***
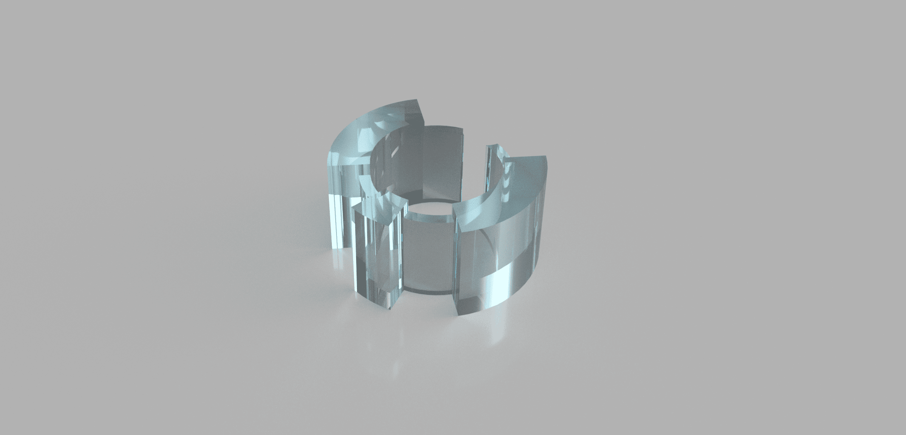
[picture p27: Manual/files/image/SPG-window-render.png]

> [!IMPORTANT]
> - Print SLA in clear resin - do not print in metal 
> - light sanding might be needed to reduce the height for best fitment. 
> - you might want to have 2x printed just in case you break one 

> [!NOTE]
> Not all SLA resin is the same, some is much more brittle or less clear. 3d printing services simplify this and typically use ultra-clear durable engineering resins. 

This part allows you to see the spinning plasma gate while protecting it from dust and debris. This is intentionally thick to magnify the internals - you can "shell" this piece for less maginification or to provide a different effect. 
Even with professional resins this piece can be brittle on the thin sections, this is drastically reduced when installed. 

## SPG-reactor
***
[to TOC &uarr;](#toc)
***
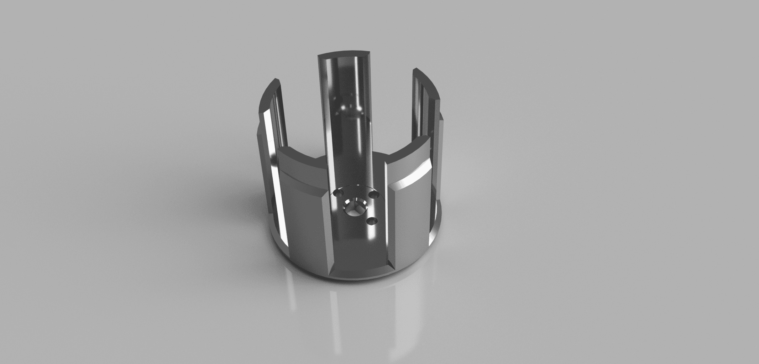
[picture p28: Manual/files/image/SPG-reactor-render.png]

> [!IMPORTANT]
> - we recommend the usage of a 3-stage 6mm micro motor - this is the best option for size and speed control 
> - this will NOT fit a 4-stage motor 

> [!NOTE]
> - This part is keyed for alignment with the SPG-collector - 1mm brass rod (with glue) can be used for pins to connect the 2 pieces 
> - polishing the inside and outside of this part helps with light transmission and reflectivity effect.

The micro motor slots into the center of this piece. the shaft hole is keyed to match the key on the micro motor. 
The bottom end of this part sits in the 7x14x5 ceramic bearing, sandwiched between the motor and bearing. 
Micro LED strips or Medium Shtok pixel rings are installed around the motor. 
clearances MUST checked to ensure free movement and that no parts are rubbing.  

## SPG-base
***
[to TOC &uarr;](#toc)
***
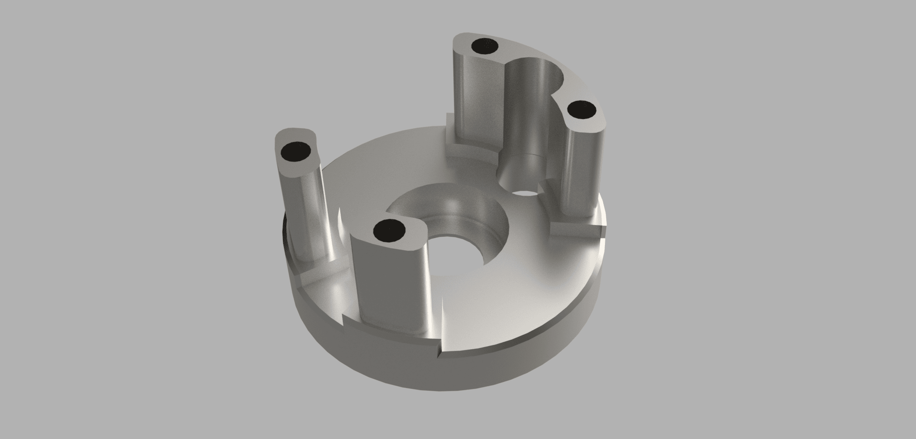
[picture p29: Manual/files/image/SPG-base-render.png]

> [!IMPORTANT]
> - the 7x14x5 ceramic bearing must be carefully glued into this piece - make sure the glue is only applied to the outside

> [!NOTE]
> - you can wrap the "posts" in 24g magnet wire for added visual effect as a containment chamber. 
> - polishing this part helps with light transmission and effect. 

This part houses the movement aspects of the plasma gate assembly and ties the crystal chamber together with the plasma gate assembly. 
you will need to glue in the bearing and SPG-reactor during assembly - this ensures durability. 

## SPG-collector
***
[to TOC &uarr;](#toc)
***
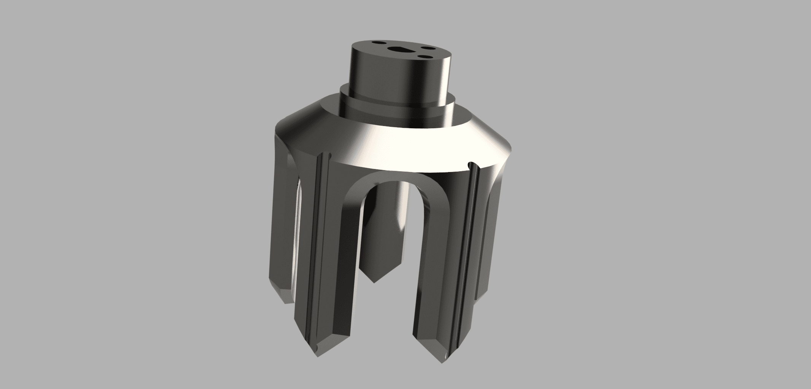
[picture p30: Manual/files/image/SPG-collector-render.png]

> [!IMPORTANT]
> - this part might need some sanding to the top surface for mating to the bottom of the SPG-reactor inside the bearing 
> - the diameter should fit snuggly in the bearing but due to printing inaccuracies it might require some sanding for press fitment. 

> [!NOTE]
> - polish this part to help reflect light from the crystal 

this is the visible exposed part that spins around the actual crystal. this is held into the bearing with a combination of glue and 3x 1mm brass rods connecting to the SPG-reactor. 

## SPG-base
***
[to TOC &uarr;](#toc)
***
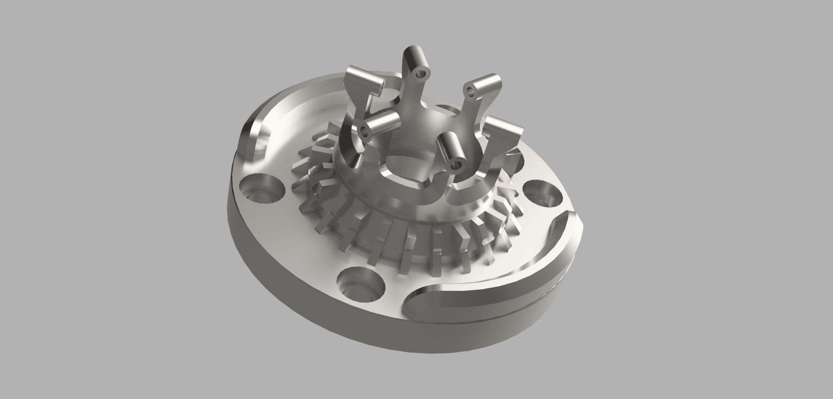
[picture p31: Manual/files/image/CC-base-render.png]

> [!IMPORTANT]
> - you can use a real quartz crystal and use a combination of glue/resin and 28g magnet wire to secure the crystal. 
> - it is not recommended to bend the prongs - 3d printed metal is very durable but may fracture if bent. 
> - make sure the crystal clears and does not touch the SPG-collector when fully installed - the SPG-collector must spin freely. 

> [!NOTE]
> - polishing this part will increase lighting effect. 
> - this is designed for a single pixel led to be mounted on the underside or beneath the crystal

This piece houses the kyber crystal, and lighting under it. This also serves as the base for the crystal chamber tying the crystal chamber to the plasma gate. 
you will need to install this to check fitment and clearance prior to final assembly. 

## SPG-fins
***
[to TOC &uarr;](#toc)
***
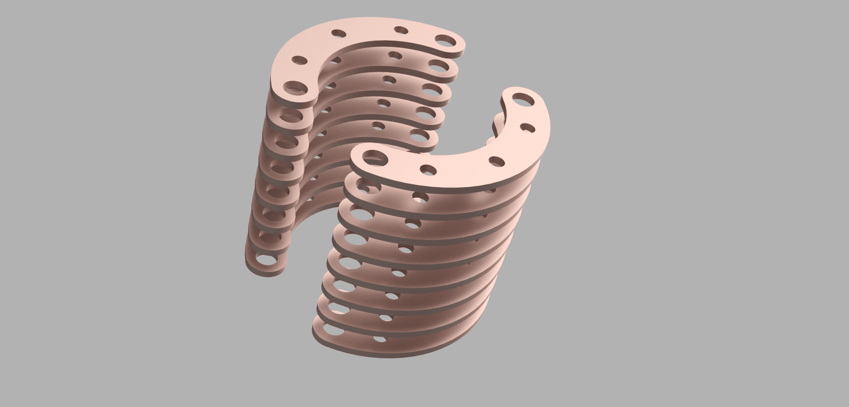
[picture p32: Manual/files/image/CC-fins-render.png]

> [!IMPORTANT]
> - This part is intended for laser cut metal parts - printing this part has NOT been tested. 
> - you will need spacers between these - 4-40 heatset inserts work well or 4-40 spacers can be used. 
> - you can use less or more "cooling fins", however 6-7 (per side, 12-14 total) fit well inside a Graflex chassis based on spacer height - you may need less or more based on fitment.

> [!NOTE]
> - polishing this part will increase lighting effect.
> - you can pick your material - brass, copper, and titanium have been tested. 

PLEASE have these laser cut, preliminary tests using 3d printed parts have provided inconsistent results and can lead to misalignment. 
If you use a threaded spacer between fins assembly and testing can be more tedious - unthreaded spacers can help with assembly.

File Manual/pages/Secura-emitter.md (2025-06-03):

# Secura Emitter
_Blade holder, buttons and chassis side blade pins_
***
## Navigation: [Manual](../README.md) / Secura-emitter.md
***
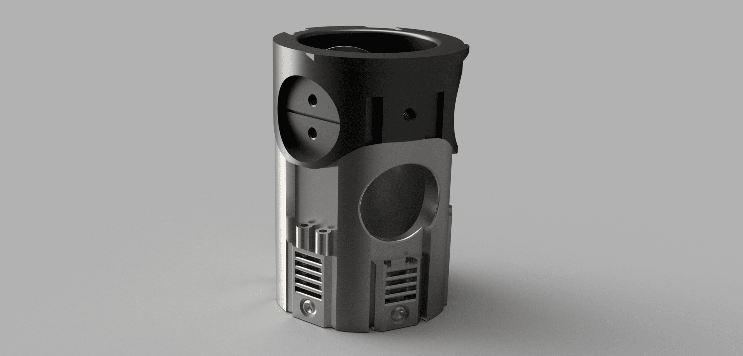
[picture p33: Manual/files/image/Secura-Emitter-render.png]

***
https://github.com/user-attachments/assets/98bedda8-689d-4d3c-846b-197768a15971
***
## Emitter Part Highlights:
> [!CAUTION]
> You will need to tap many holes in this part. 
> - 4-40 = threaded rods for body support/assembly and to hold the button cover on. 
> - 3-48 = brass pins 

> [!IMPORTANT]
> - It is our strong recommendation to have the chassis parts SLM printed from metal 
> - you only need to print ONE top part, either accurate or without rear notches

***

## TOC
[Manual](../README.md) / Secura-emitter.md
- Top (_pick one_)
  - [EM-topAccurate ](#em-topaccurate) - ALT has accurate rear cutouts 
  - [EM-top ](#em-top) - ALT does not have rear cutouts + more of a fillet
- [EM-base](#em-base)
- [EM-button](#em-button)

## EM-topAccurate
***
[to TOC &uarr;](#toc)
***
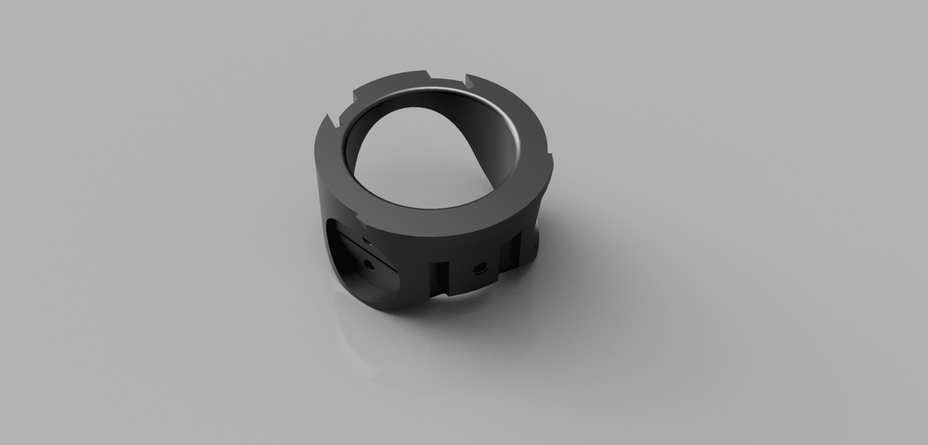
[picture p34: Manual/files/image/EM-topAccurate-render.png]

> [!IMPORTANT]
> the inner diameter will be TIGHT and require sanding to fit a 1"blade - 25.4mm diameter.

> [!NOTE]
> you will need to have this coated/anodized to make it black.

Designed to be an accurate representation of the original Graflex upper - some dimensions may be a little off, I do not have a vintage assembly to compare to. 

## EM-top (alternate)
***
[to TOC &uarr;](#toc)
***
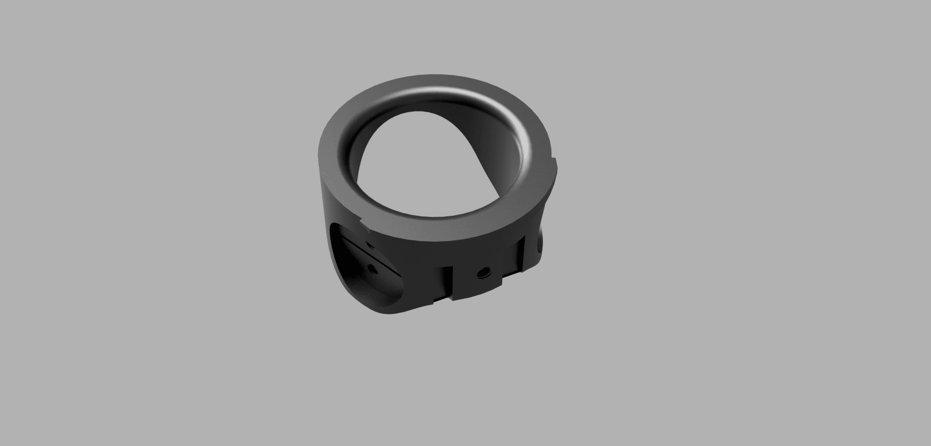
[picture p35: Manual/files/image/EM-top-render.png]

> [!IMPORTANT]
> the inner diameter will be TIGHT and require sanding to fit a 1"blade - 25.4mm diameter.

Designed to have a more rounded entrance for the blade to enter, without the cutouts in the rear. 
> [!NOTE]
> you will need to have this coated/anodized to make it black. 

## EM-base
(image shows top and bottom)
***
[to TOC &uarr;](#toc)
***
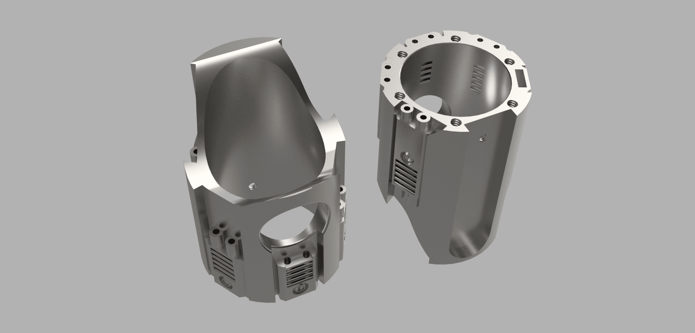
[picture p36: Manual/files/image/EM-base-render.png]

> [!IMPORTANT]
> the inner diameter will be TIGHT and require sanding to fit a 1"blade - 25.4mm diameter.

> [!CAUTION]
> the 4-40 holes on the bottom are blind holes, meaning you will need to clear the chips out or you will snap a tap. 
> Additionally, we highly recommend SLM Aluminium - Stainless and Titanium are VERY hard to tap unless you are experienced
> YOU. HAVE. BEEN. WARNED.

https://github.com/user-attachments/assets/6ad42594-aa53-4170-b123-81a9c08d6567

- The emitter is designed with more holes than we need for this project, this was to allow its usage on other projects and chassis. 
- If using for this project you will only need to tap 4x holes, the 2x under the glass eye and the 2x beside the button groove. 
- 1mm brass rod can be used to add accents with the numerous holes throught the "venting" areas. 
- You will need to tap the rear hole 4-40 for a screw to hold the button cover in place - this is not a blind hole and very easy to tap. 
- there is a slot to use a levered microswitch for the alt button, you will need to drill holes (1.2mm) or use glue to mount this. Alternatively you can use other switches but this has not been tested.

## EM-button
(image shows top and bottom)
***
[to TOC &uarr;](#toc)
***
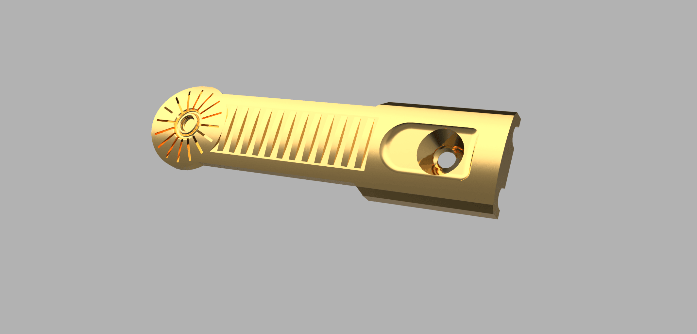
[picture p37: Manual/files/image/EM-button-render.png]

> [!IMPORTANT]
> depending on button selection you may need to sand the emitter then shim under this part to provide clearance.

The button covers the tactile button and is thin enough to bend slightly to actuate the button. A 4-40 screw holds this in place and will need to be ground down so it doesn't protrude into the blade area.

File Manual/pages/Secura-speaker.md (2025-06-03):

# Secura Speaker
_28mm or 33mm Shtok Titan options_
***
## Navigation: [Manual](../README.md) / Secura-speaker.md
***
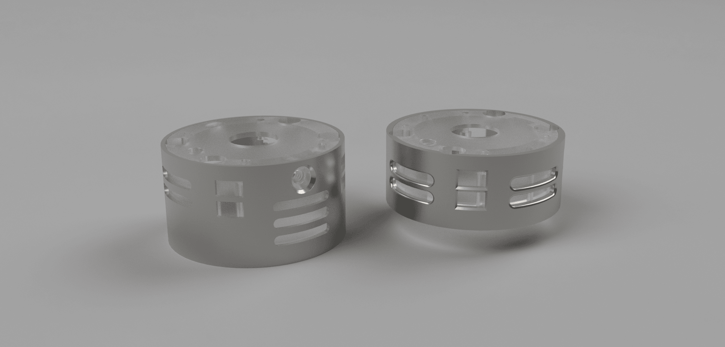
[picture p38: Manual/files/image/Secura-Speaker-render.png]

***
## Emitter Part Highlights:
> [!CAUTION]
> - Pick ONE: 33mm for Shtok titan or 28mm 
> - we have tested many 28mm speakers but some may not fit. 

> [!IMPORTANT]
> - for the 33mm version it is highly recommended to use SLM printed metal - plastic/resin tests have not been successful

> [!TIP]
> The sound quality and output produced by the Shtok 33mm Titan is unmatched - it is much trickier to build but has great rewards.

***

## TOC
[Manual](../README.md) / Secura-speaker.md

pick ONE: 
- [33mm Shtok Titan](#sp-33mm)
  - [SP-33mm-outer ](#sp-33mm-outer) 
  - [SP-33mm-holder ](#sp-33mm-holder) 

- [28mm Speaker](#sp-28mm)
  - [SP-28mm-outer](#sp-28mm-outer)
  - [SP-28mm-holder](#sp-28mm-holder)

***

# SP-33mm

https://github.com/user-attachments/assets/73da1abb-a244-40c8-bd3c-021bff45e680

## SP-33mm-outer
***
[to TOC &uarr;](#toc)
***
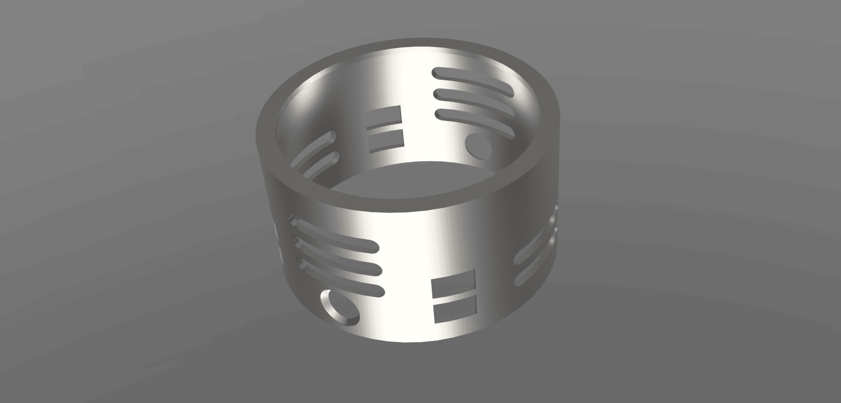
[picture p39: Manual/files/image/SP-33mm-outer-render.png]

> [!IMPORTANT]
> - you will need to sand the internal diameter for fitment.
> - this is a VERY tight fit, take your time

> [!NOTE]
> you may need to gently file the edge of the speaker basket for perfect fitment .

This houses the Shtok 33mm titan speaker and is a very tight fit, the metal is thin and needs to be treated very carefully. 
this part is held into the SP-33mm-holder with 2x 4-40 screws - you will likely need to cut the screws down so they dont bottom out on the speaker

## SP-33mm-holder
***
[to TOC &uarr;](#toc)
***
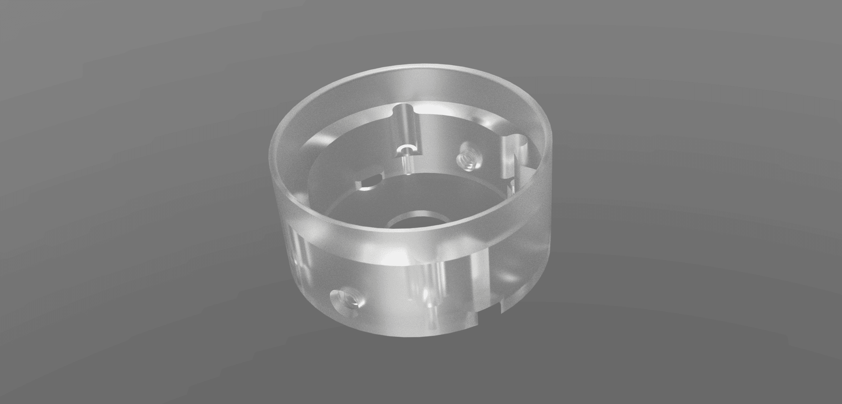
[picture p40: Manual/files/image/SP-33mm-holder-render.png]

> [!IMPORTANT]
> - this must be printed from a transparent/translucent material if you want to use a light at the base of the saber.
> - you may need to sand the external to fit in the SP-33mm-outer part 

> [!NOTE]
> there is very little room for extra wire slack, it is recommended to run the wires and solder in place then pack the speaker in .

This houses the Shtok 33mm titan speaker and is a very tight fit. this part gets attached to the CH-base part with 4x m1.4 screws  

# SP-28mm

https://github.com/user-attachments/assets/f698026a-3095-47ef-9c3f-5bcf8754eda8

## SP-28mm-outer
***
[to TOC &uarr;](#toc)
***
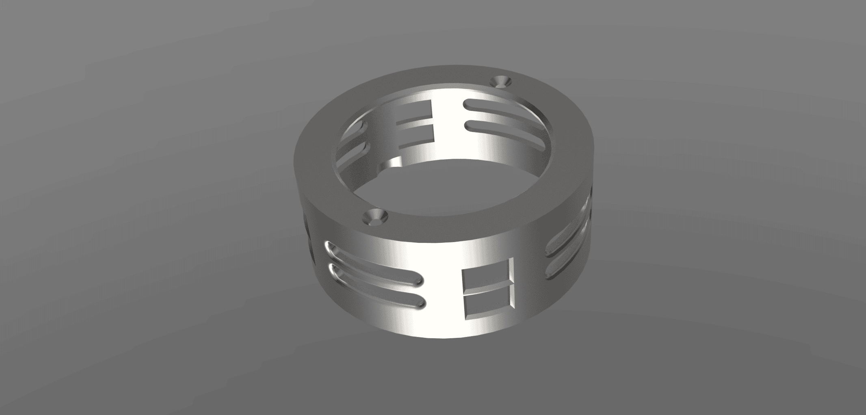
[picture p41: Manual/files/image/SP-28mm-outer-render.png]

> [!IMPORTANT]
> - you might need to sand the internal diameter for fitment.

> [!NOTE]
> the cover is held on with 2x m1.4 screws - do not over tighten 

this part houses the SP-28mm-holder and uses 2x m1.4 screws to secure in place. A tight fitment is ideal and relieves stresses on the m1.4 screws.

## SP-28mm-holder
***
[to TOC &uarr;](#toc)
***
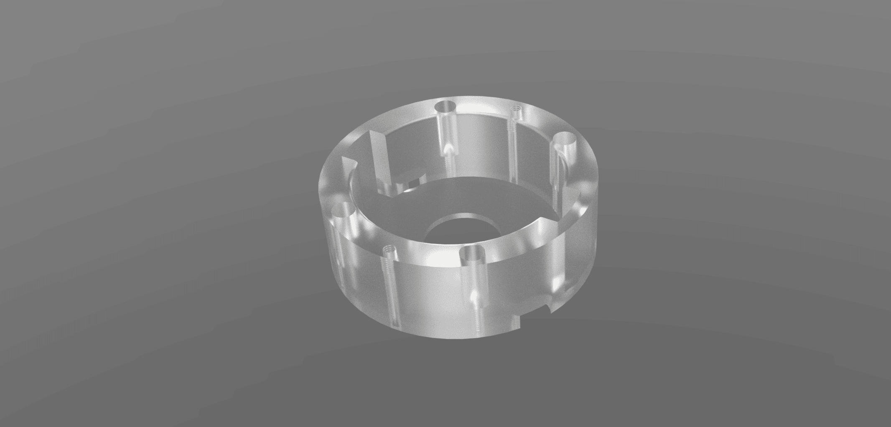
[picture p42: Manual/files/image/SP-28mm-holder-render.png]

> [!IMPORTANT]
> - this must be printed from a transparent/translucent material if you want to use a light at the base of the saber.
> - you may need to sand the external to fit in the SP-28mm-outer part

> [!NOTE]
> there is very little room for extra wire slack, it is recommended to run the wires and solder in place then pack the speaker in .

This houses _most_ 28mm speakers, we have tested many variations but there may be 28mm speakers that do not fit.

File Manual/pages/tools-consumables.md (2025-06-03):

# Tools
***
## Navigation: [Manual](../README.md) / Tools.md
***

Recommended tools for assembly - this is NOT about brands, but the functional underlying tool. We might make recommendations on brand solely because we find it to be better in some way, but that does not mean another manufacturer could be just as good or better. 

## TOC
[Manual](../README.md) / Tools.md
- [Soldering](#soldering)
- [Tools](#tools)
- [Tooling](#tooling)
- [Consumables](#consumables) 

***
## Soldering
***
> [!IMPORTANT]
> - Parts marked as "required" will be needed
> - Parts marked as "optional" will make the job easier

| **Item** | **Required** | **URL Example** | **NOTES** |
|---|---|---|---|
| Soldering Iron | YES | https://a.co/d/9zlUuRT  | 2-part units are ideal here, nothing fancy |
| Solder - rosin core | YES | https://a.co/d/3S0uKSS  | prefer lead free or 70/30 |
| Flux paste | Optional | https://a.co/d/8E23tCn  | not required, but makes life so much easier |
| Soldering Mat | Optional | https://a.co/d/bVDmoHY  | not required, good for organization and heat resistance |
| Soldering tip cleaner | YES | https://a.co/d/ho6Ssim  | KEEP YOUR TIP CLEAN - clean soldering = better joints.  |

> [!CAUTION]
> - We DO NOT recommend using flux on your soundboard - improper cleanup can lead to component malfunctions

[to TOC &uarr;](#toc)

***
## Tools
These are the recommended tools - we split out "[tooling](#tooling)" (drill bits, taps etc. below.) 
***
> [!IMPORTANT]
> - Parts marked as "required" will be needed
> - Parts marked as "optional" will make the job easier
> - Any items without links is due to either the item not being offered, or most anything will do, or I use a prohibitively expensive version that you don't need. 
> - By NO MEANS do you need to order from Amazon, it was just easy to link for a visual reference. 

| **Tool** | **Required** | **URL Example** | **NOTES** |
|---|---|---|---|
| Rotary Tool | YES | https://a.co/d/2nm2uB2 | This is ESSENTIAL - grinding, polishing, and some drilling. DO NOT get battery operated or handheld |
| Hand Drill | Optional | | Ideal to have for cleaning holes or making holes - not required but ideal |
| Desk Vice | YES | https://a.co/d/5fvYBJJ | not required, but makes life so much easier |
| Wire Clippers flush cut | YES | https://a.co/d/fGOCyjD | Required, buy good = buy once |
| Wire Strippers | YES | https://a.co/d/dnWjO9M | required, the linked pair is very good for small and large wire work |
| Pliers | YES | https://a.co/d/epeQHWq | Get a set, you will want a few variations. Small tips are ideal |
| Mini (needle) Files | YES | | small spaces = small files. Larger files can be used for larger changes |
| Tech Tweezers | YES | | get good strong + thick tech tweezers with a few different bends and tips. fine point is good sometimes and round tip is good other times |
| Digital Calipers | Optional | https://a.co/d/hMzxBf9 | Though not required, VERY good to have for exacting changes. the linked pair is very good at a reasonable price. |
| Tech screwdriver set | YES | https://a.co/d/7auFY8b | A set will have more than you need for this, but having a set will solve many future issues. |
| Tap handle(s) | YES | https://a.co/d/gbsMQYj | you will use all small taps, a single small handle will do. Linked one covers all |
| Magnifying glass/digital microscope | Optional | | I prefer a digital microscope, not cheap but very effective |
| Surface Plate | Optional | https://a.co/d/3rCB6aC | NOT needed, you could just buy a single granite tile or use a counter top - for sanding parts flat for best mating. |

> [!NOTE]
> - This is by no means an exhaustive list.

[to TOC &uarr;](#toc)

***
## Tooling
The tooling you use with the above list of tools 
***
> [!IMPORTANT]
> - Parts marked as "required" will be needed
> - Parts marked as "optional" will make the job easier
> - Any items without links is due to either the item not being offered.
> - By NO MEANS do you need to order from Amazon, it was just easy to link for a visual reference.

| **Tooling** | **Required** | **URL Example** | **NOTES** |
|---|---|---|---|
| 4-40NC tap and drill | YES | https://a.co/d/fnsp2cP | for the blade retention screw + 4-40 rods. Drill and then tap, 3d SLM is not perfect. |
| #3-48 Tap and drill | YES | https://a.co/d/dVFXWlp | For the graflex brass pins |
| M1.4 x 0.3mm | YES | https://a.co/d/728u6F4 | to hold on the speaker enclosure - VERY fragile, take your time |
| Cobalt Drill Bits 1.4mm | Optional | https://a.co/d/j2wcuOR | to secure the secondary micro switch - optional based on how you implement that. |
| 10Pcs Carbide Burr Set  | YES | https://a.co/d/fVOcT8a | required, good for cleaning print mistakes, sharp edges etc. |

> [!CAUTION]
> - Tapping metal is difficult and requires precise alignment - failure to do so will snap your tap and may (will likely) scrap your piece
> - Tapping Difficulty increases with metal selection - Stainless and Titanium are VERY difficult - you WILL snap taps. 

[to TOC &uarr;](#toc)

***
## Consumables
Remainder of items that you will use 
***
> [!IMPORTANT]
> - Items marked as "required" will be needed
> - Items marked as "optional" will make the job easier
> - Any items without links is due to either the item not being offered.
> - By NO MEANS do you need to order from Amazon, it was just easy to link for a visual reference.

| **Consumables** | **Required** | **URL Example** | **NOTES** |
|---|---|---|---|
| Heatshrink | YES | https://a.co/d/6uo7OrU | I prefer clear for joint inspection if something comes dislodged in the future |
| Liquid electrical tape | YES | https://a.co/d/btpSdsn | good for isolating parts from the metal chassis |
| E6000 or E7000 | YES | https://a.co/d/2C9wNKP | Glue in various parts (bearing, hilt pixel assembly, etc.) |
| JB Weld | Optional | https://a.co/d/6Hv9fzI | Good to have on hand if you break a tap and dont want to scrap a piece |
| LocTite (blue) | YES | https://a.co/d/gga7cAJ | Use for threads - I use blue, you can use purple but its not as strong |
| Abrasive Buffing/Polishing | YES | https://a.co/d/iFB9eet | Use after you have done most of the sanding to finish surfaces |
| Sanding Drum set (sm+lg) | YES | https://a.co/d/hvZ34o2 | you will do lots of sanding, this will help a ton. |
| Cutting wheel | Optional | https://a.co/d/9DIWIUj | Cutting tubes, 4-40 rods and similar items. |
| 28G PTFE wire | YES | https://a.co/d/6ipNtxO | Highly recommend Remmington, by far the best. Use PTFE, its the smallest. |
| 18G PTFE Wire | YES | https://a.co/d/cuWiQli | I recommend 18g for main blade power and ground, you can use 20g for lower power handling |
| Sandpaper - wet/dry | YES | | 120 grit to 600 grit recommended |
| Tap Cutting Fluid | YES | https://a.co/d/iyP1SfD | this is essential to not break taps - use the fluid, dont play games |
| Simple Green (degreaser) | YES | https://a.co/d/d57eDAd | remove grease after tapping or finish prep |

> [!NOTE]
> - More is more - you cannot have too many finishing consumables  

[to TOC &uarr;](#toc)

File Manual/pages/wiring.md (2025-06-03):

# Wiring
***
## Navigation: [Manual](../README.md) / Wiring.md
***

Recommended tools for assembly - this is NOT about brands, but the functional underlying tool. We might make recommendations on brand solely because we find it to be better in some way, but that does not mean another manufacturer could be just as good or better.

## TOC
[Manual](../README.md) / Wiring.md
- [Blade Wire Gauge](#blade-wire-gauge)
- [Chassis Wire Gauge](#chassis-wire-gauge)
- [Wiring Diagram](#wiring-diagram)

***
## Blade Wire Gauge
***
> [!IMPORTANT]
> - This is for wiring the positive and negative connections from the chassis neopixel connector to the battery/board
> - Smaller gauge = thicker = harder to work with and route, choose carefully 
> - Assumes a standard 143 pixel per-strip
> - Assumes "white" as a blade style for maximum draw 
> - these are safe values, you can get away with less but we recommend safe.

| **LED Strip Count** | **AMPS** | **Single Wire Gauge** | **Double Wire Gauge** | **NOTES** |
|---|---|---|---|---|
| 1 x 143 pixels | 5.2 | 22g | - | not recommended |
| 2 x 143 pixels | 10 | 20g | 2x 24g | Most common for standard blades and pixel sticks |
| 3 x 143 pixels | 14.5 | 18g-19g | 2x 23g | Ideal for more complex blades and pixel sticks |
| 4 x 143 pixels | 18 | 16g-18g | 2x 22g | Slightly overkill, but 18g will handle most anything you throw at it - this is what i use. |
| 5 x 143 pixels | 20.5 | 16g or lower | 2x 20g | extreme and untested in this chassis |

> [!CAUTION]
> - High amp connections can present dangerous conditions - proceed carefully. 
> - undersized wires can cause the wires to overheat causing an equally dangerous scenario 
> - make sure your battery supports the amp rating for CONSTANT draw 

[to TOC &uarr;](#toc)

***
## Chassis Wire Gauge
***
> [!IMPORTANT]
> - In many cases I use 28G for the remainder if the internals 
> - these are approximate ranges, you should always do the appropriate calculations 

| **Chassis Part** | **Wire Gauge** | **NOTES** |
|---|---|---|
| Accent LEDs | 28-30g | I use 30g for data and 28g for power/ground |
| OLED | 28g | you can use 30g but I have had better success with 28g |
| Speaker | 26-28g | even with a large speaker (33mm) the 28g does a perfect job |
| Micro motor | 28-30g | 30g is fine, but 28 will fit and work well |
| switches | 28-30g | 30g is fine, but 28 will fit and work well |

> [!CAUTION]
> - pay attention to your wires, dont fry your board. 

[to TOC &uarr;](#toc)

***
## Wiring Diagram
***
> [!IMPORTANT]
> - this my not be the most elegant way to do things - you can likely combine some wires
> - I recommend explicit wires instead of wire-sharing, this eliminates wire noise

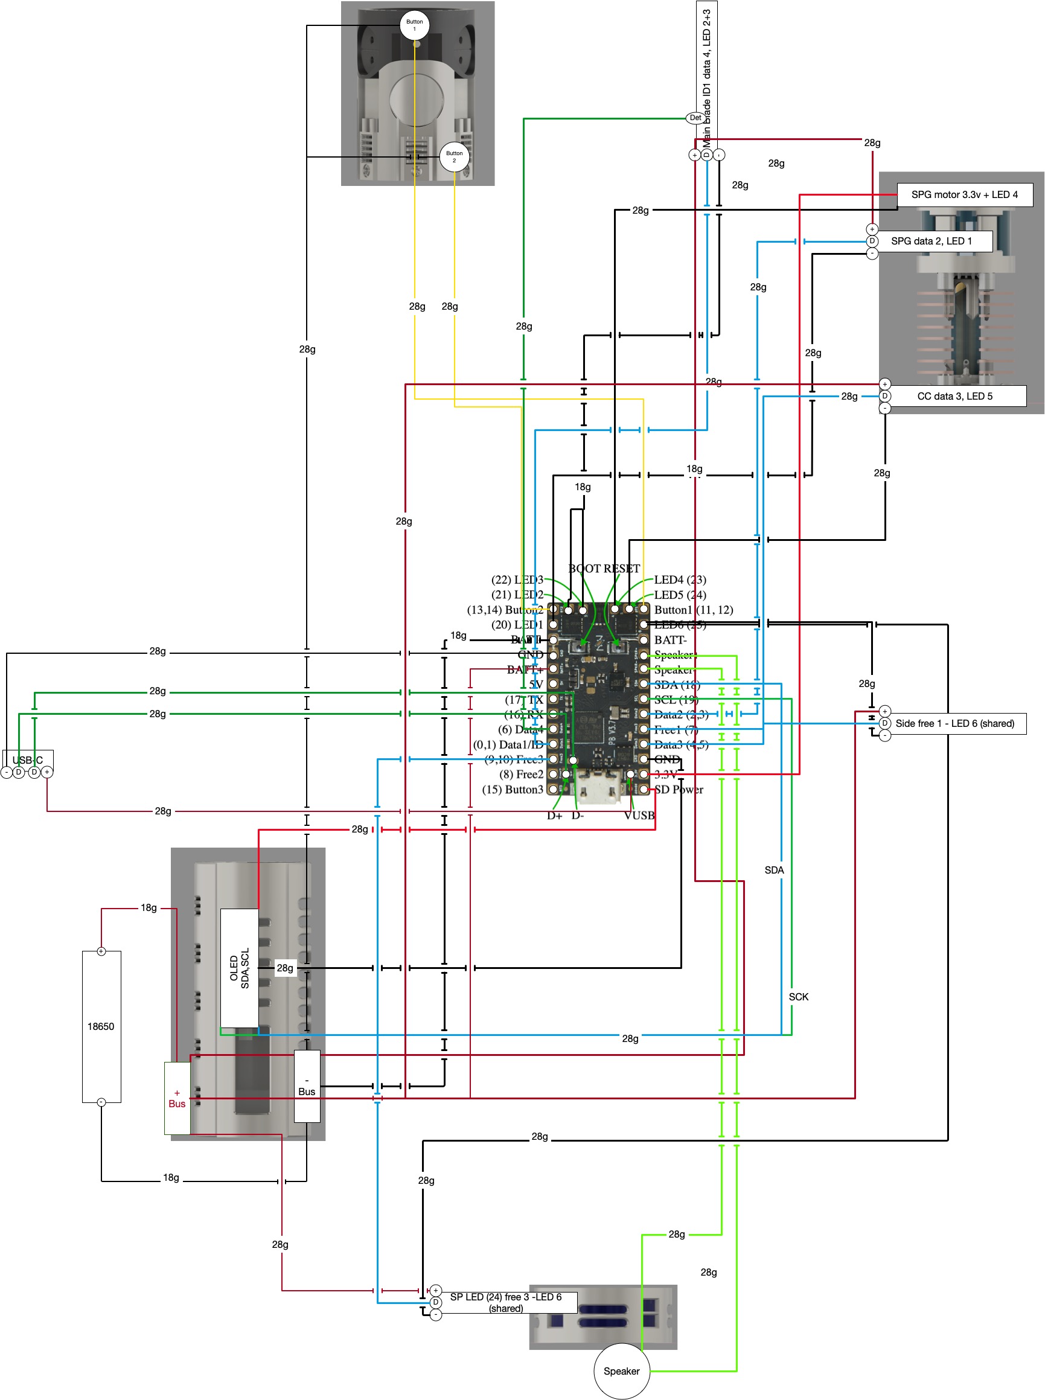
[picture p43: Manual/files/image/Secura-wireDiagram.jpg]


[Secura-wireDiagram.pdf](https://github.com/user-attachments/files/20558570/Secura-wireDiagram.pdf)

> [!CAUTION]
> - pay attention to your wires, dont fry your board.

[to TOC &uarr;](#toc)

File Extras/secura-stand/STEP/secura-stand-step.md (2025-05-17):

this is the solid model file for the saber stand

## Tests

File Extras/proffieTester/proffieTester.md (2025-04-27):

half baked proffie tester. 
- designed to use glued in spring terminals
- inset for circuit board
- use pogo pins to secure the board
- leverage a magnet to hold the board down (needs a better method) 
- place for a 28mm speaker
- place for an OLED screen
- will accept standarg graflex blade adaptors to retain the neopixel testing

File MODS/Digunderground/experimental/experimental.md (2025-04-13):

EXPERIMENTAL - UNTESTED and in process ideas

DO NOT assume these work, they do not. This is a proving ground for ideas. 
Print or use at your own risk.

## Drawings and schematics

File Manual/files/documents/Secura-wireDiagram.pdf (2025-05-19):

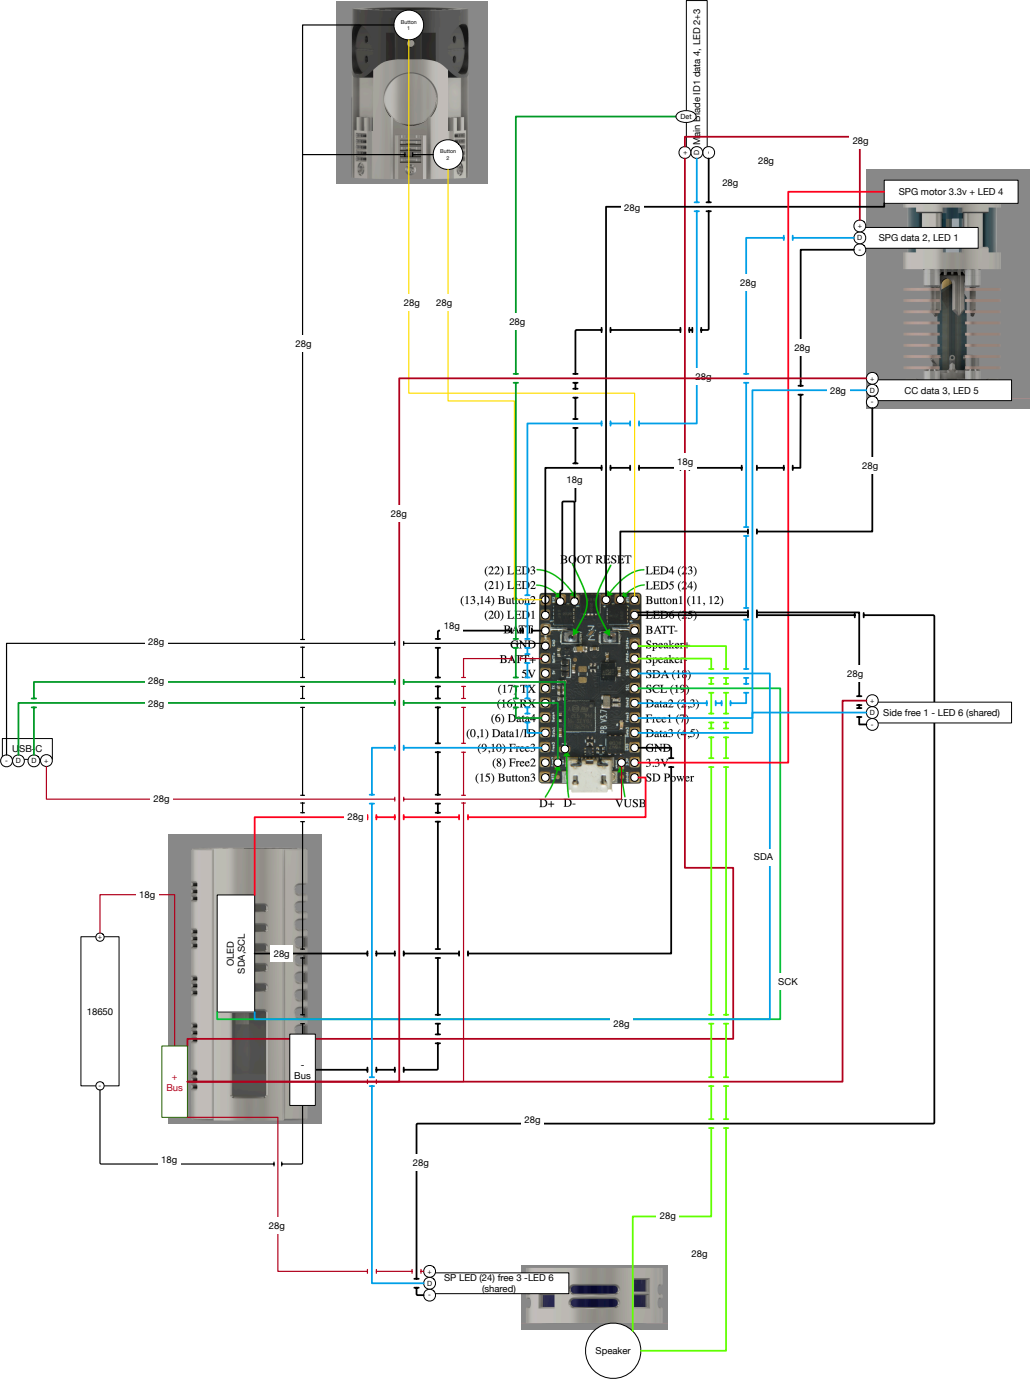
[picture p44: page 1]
Button 2; Button 1; SPG data 2, LED 1; Speaker; OLED; SDA,SCL; Bus; SDA; SCK; Det; SP LED (24) free 3 -LED 6 (shared) -; USB-C; Side free 1 - LED 6 (shared)

Main Blade ID1 data 4, LED 2+3

SPG motor 3.3v + LED 4

CC data 3, LED 5

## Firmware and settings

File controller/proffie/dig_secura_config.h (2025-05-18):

// ProffieOS7 Config File
#ifdef CONFIG_TOP
#include "proffieboard_v3_config.h"
//#include "dig-styles.h"
/*--------------------------------- Blade Config ---------------------------------*/
#define BLADE_DETECT_PIN 6 // insertion & removal
#define NUM_BLADES 6
#define NUM_BUTTONS 2
const unsigned int maxLedsPerStrip = 300; // 144 = base
#define EXTRA_COLOR_BUFFER_SPACE 60
// for blade ID
#define SHARED_POWER_PINS
#define BLADE_ID_SCAN_MILLIS 1000
#define BLADE_ID_TIMES 10
#define ENABLE_POWER_FOR_ID PowerPINS<bladePowerPin2, bladePowerPin3>
// USE:
/*
BladeConfig blades[] = {
      { 5000,
        WS281XBladePtr<132, bladePin, Color8::GRB, PowerPINS<bladePowerPin2, bladePowerPin3> >(),
        CONFIGARRAY(blade1_in) },
      { 10000,
        WS281XBladePtr<128, bladePin, Color8::GRB, PowerPINS<bladePowerPin2, bladePowerPin3> >(),
        CONFIGARRAY(blade2_in) },
      { NO_BLADE,
        WS281XBladePtr<144, bladePin, Color8::GRB, PowerPINS<bladePowerPin2, bladePowerPin3> >(),
        CONFIGARRAY(no_blade) },
    };
*/
/*--------------------------------- Volume Config ---------------------------------*/
#define VOLUME 2500 // 33mm = 3000 28mm = 2500
#define BOOT_VOLUME 600
#define FILTER_CUTOFF_FREQUENCY 100
#define FILTER_ORDER 4 //orig 8
/*--------------------------------- Power Save ---------------------------------*/
#define MOTION_TIMEOUT 60 * 15 * 1000
#define IDLE_OFF_TIME 60 * 15 * 1000
//#define PLI_OFF_TIME 30 * 1000 //  Controls how long battery display is shown on OLED after animations end.
/*--------------------------------- base Enable / Disable ---------------------------------*/
#define ENABLE_AUDIO
#define ENABLE_MOTION
#define ENABLE_WS2811
#define ENABLE_SD
//#define DISABLE_BASIC_PARSER_STYLES // disable OOTB parser styles
#define ENABLE_BASIC_PARSER_STYLES
#define DISABLE_DIAGNOSTIC_COMMANDS // disable logging
#define ENABLE_ALL_EDIT_OPTIONS
#define SAVE_PRESET
#define NO_REPEAT_RANDOM
#define FETT263_SAY_BATTERY_PERCENT
/*--------------------------------- OLED ---------------------------------*/
#define ENABLE_SSD1306
//#define OLED_FLIP_180
//#define USE_AUREBESH_FONT // use Aurebesh font on OLED
/*--------------------------------- Bluetooth ---------------------------------*/
//#define ENABLE_SERIAL
//#define BLE_PASSWORD "12345"
//#define BLE_NAME "digsaber"
//#define BLE_SHORTNAME "digsaber"
/*--------------------------------- On-Saber Settings method ---------------------------------*/
#define FETT263_DISABLE_COPY_PRESET //- Disables the "on-the-fly" Copy Preset option
// #define FETT263_DISABLE_CHANGE_FONT //- Disables the "on-the-fly" Change Font option
// #define FETT263_DISABLE_CHANGE_STYLE //- Disables the "on-the-fly" Change Style option
/* OPT 1 ====================*/
#define FETT263_EDIT_MODE_MENU // Edit ALL settings like blades, color
/* OPT 2 ====================*/
//#define FETT263_EDIT_SETTINGS_MENU // edit base settings IE volume, brightness

/*--------------------------------- Blade Color / Multiphase ---------------------------------*/
/* OPT 1 ====================
#define FETT263_MULTI_PHASE // allows color wheel - cannot use with FETT263_SPECIAL_ABILITIES - swap if stuff stopps working */
/* OPT 2 ====================*/
#define FETT263_SPECIAL_ABILITIES // need for kyber/multi select - remove if unused
//
#define COLOR_CHANGE_DIRECT //no color wheel? Needed for special ability color change?
#define FETT263_USE_BC_MELT_STAB // melt is full-time gesture controlled.
/*--------------------------------- Power Button control ---------------------------------*/
#define FETT263_MOTION_WAKE_POWER_BUTTON
//#define FETT263_HOLD_BUTTON_OFF // instant off for power?
/*--------------------------------- Motion Action(s) ---------------------------------*/
#define FETT263_SWING_ON
#define FETT263_TWIST_ON_PREON
#define FETT263_TWIST_OFF
/*--------------------------------- Action Speed ---------------------------------*/
#define FETT263_LOCKUP_DELAY 200
#define FETT263_BM_CLASH_DETECT 10 // higher = battlemode uses clash even for hard hits. lower locks up easier
#define FETT263_SWING_ON_SPEED 300 // orig 250
#define CLASH_THRESHOLD_G 2.5 // previous = 3.0
#define AUDIO_CLASH_SUPPRESSION_LEVEL 1 // new addition https://crucible.hubbe.net/t/whats-the-minimum-clash-threshold-can-be-adjusted-and-or-set-to/3268/3
#define KILL_OLD_PLAYERS
#endif

#ifdef CONFIG_PROP
#include "../props/saber_fett263_buttons.h"
#endif

/*--------------------------------- Blade Presets = Blade ---------------------------------*/
// use blade style functions
// main blade is WITH a blade inserrted
// no_blade is for when the blade is removed - turns off SPG motor and other accents
// for help use https://pod.hubbe.net/config/preset-configuration.html
#ifdef CONFIG_PRESETS
Preset presets[] = {
{ "FONT_NAME;common",  "",
StylePtr<BladeStyleFunctionGoesHere>(),
StylePtr<Black>(),
StylePtr<Black>(),
StylePtr<Black>(),
StylePtr<Black>(),
StylePtr<Black>(),
"name on\n screen"
},
};
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

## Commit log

2025-03-06 Create Secure Chassis Lore.md
2025-03-25 Update-Secure Chassis Lore.md
    corrected story for adherence to cannon
2025-03-26 R1-beta release
    closed beta - pre release
    [Secura-BH-R1 v2.f3d, Secura-CC-SPG-R1.f3d, Secura-CH-R1.f3d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]
2025-03-26 INIT bom listing - WIP
    [BOM.xlsx]
2025-03-26 init - closed beta
    untrested 33mm variant.
    [CC - Base.stl, CH - Chassis.stl, CH - Electronics Door.stl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]
2025-03-26 init
    DXF files for laser cut metal pieces
    [Secura-cc-fins.dxf, Secura-pg-hex-mesh.dxf]
2025-03-26 update current and TODO
2025-03-26 Update and rename cad.md to README.md
2025-03-27 uploaded STEP for non F360 users
    [Secura-SP-R1.step]
2025-03-27 update order + current progress.
2025-04-13 EXPERIMENTAL - 21700 chassis
    needs a bunch of work to house electronics as the back wall is missing - uploading to preserve the files for future work.
    [CH - Chassis-21700.stl, CH - battery door- 21700.stl]
2025-04-13 EXPERIMENTAL not working
    21700 test for the chassis - this needs a lot of work. Saving here for future iteration.
    [Secura-CH-EXP-21700-Chassis.step, Secura-CH-EXP-21700-batteryDoor.step]
2025-05-11 Add files via upload
    INIT
    [Secura_Stand_v2_arc-holder.stl, Secura_Stand_v2_arc-large.stl, Secura_Stand_v2_base.stl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]
2025-05-17 Delete Extras/secura-stand/STL/Secura_Stand_v3_arc-large.stl
    updating and removing version from file name
    [Secura_Stand_v3_arc-large.stl]
2025-05-17 Delete Extras/secura-stand/STL/Secura_Stand_v2_outer.stl
    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
    [Secura_Stand_v2_outer.stl]
2025-05-17 Delete Extras/secura-stand/STL/Secura_Stand_v2_light.stl
    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
    [Secura_Stand_v2_light.stl]
2025-05-17 Delete Extras/secura-stand/STL/Secura_Stand_v2_detail.stl
    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
    [Secura_Stand_v2_detail.stl]
2025-05-17 Delete Extras/secura-stand/STL/Secura_Stand_v2_arc-holder.stl
    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
    [Secura_Stand_v2_arc-holder.stl]
2025-05-17 Delete Extras/secura-stand/STL/Secura_Stand_v2_base.stl
    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
    [Secura_Stand_v2_base.stl]
2025-05-17 Delete Extras/secura-stand/STL/Secura_Stand_v2_chassis.stl
    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
    [Secura_Stand_v2_chassis.stl]
2025-05-17 my final print files
    left extra room internally if you want to add other electronics. designed to print with a multi-filament printer/toolchanger/IDEX - work will need to be done to make the "light" bar more accessible f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
    [Secura_Stand_Arc-large.stl, Secura_Stand_arc-holder.stl, Secura_Stand_base-combined.stl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]
2025-05-17 updating directory structure: - move "experimental" under a user directory under "MODS"
    [CH - Chassis-21700.stl, CH - battery door- 21700.stl, Secura-CH-EXP-21700-Chassis.step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]
2025-05-17 - Updated naming convention for better automated export - made final edits to remove it from BETA release
    [CH - Chassis.stl, CH - Electronics Door.stl, CH - ISO - Battery.stl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]
2025-05-18 -reorg folder structure to put STEP and F360 under CAD in folders. Moved the stand into "Secura" locations as it is part of the overall concept. - fixed naming conventions across the board for more s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
    [CC - Base.stl, CC-base.stl, EM - Base.stl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]
2025-05-18 - removed styles from config - reformatted and updated for the correct pins - added additional explanations - made more general for users.
    [dig_secura_config.h]
2025-05-19 base wiring diagram - not optimized but works well. Some grounds/power may be able to be combined, wanted to avoid noise so went with "safe"
2025-05-27 all ISO parts documented - working on chassis main parts now.
2025-05-27 Update Secura-chassis.md
    had to add MP4 direct -
2025-05-27 updated all parts for the chassis
2025-05-27 Update Secura-emitter.md
    added exploded views as user-attachments
2025-05-28 Updated for crystal chamber and plasma gate
2025-05-28 Update Secura-crystalChamber.md
    Added exploded view under user attachments
2025-05-28 updated details for the Secura SP assembly.
2025-05-29 Update structure to move the manual to the build root - I may update "build" to Manual" in the future.
    [BOM.xlsx]
2025-05-29 Updated "build" to "manual"
    [BOM.xlsx]
2025-06-01 Manual updates + STL for fins and one piece fins - apologies on not swapping branches and splitting the commit.
    [NOP-CC-coolingFin-single.stl, NOP-CC-fins-l.stl, NOP-CC-fins-r.stl]
2025-06-02 updated tools + consumables and general wiring details, testing
2025-06-02 Update wiring.md
    uploaded wiring diagram as a user attachment
2025-06-03 refactor structure
    [BOM.xlsx]
2025-06-05 Thumbscrew based emitter - as requested by DLCProps. this is untested and will remain in mods for now.
    [EM-base-thumbScrew.stl]
